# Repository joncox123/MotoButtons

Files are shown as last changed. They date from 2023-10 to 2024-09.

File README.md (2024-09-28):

# MotoButtons

## Work on MotoButtons 2 is complete. The new [repository is here](https://github.com/joncox123/MotoButtons2/tree/main).

### Updates
- 3/24/2024: MotoButtons 2 design is starting. This will include a 3D printed case with mount, commercial waterproof 4-way joystick, 3 buttons (non-LED) and separate RGB LED to indicate modes. Rechargeable LiPo battery is being considered as an option.
- 3/4/2024: Media (music) mode has been added as a forth mode.
A low cost, waterproof, Bluetooth (BLE) controller for [Drivemode Dashboard](https://www.drivemodedashboard.com/) and [MyRoute App](https://www.myrouteapp.com/) motorcycle navigation with joystick and mouse mode. The cost is only $28 in parts.

**At this time, in order to use with Drivemode Dashboard, you must [install the DMD2 beta version](https://youtu.be/bJglvH23oGI?feature=shared&t=128) from the Google Play Store. To do this, join the beta program at the bottom of the DMD2 app page in the Play Store**

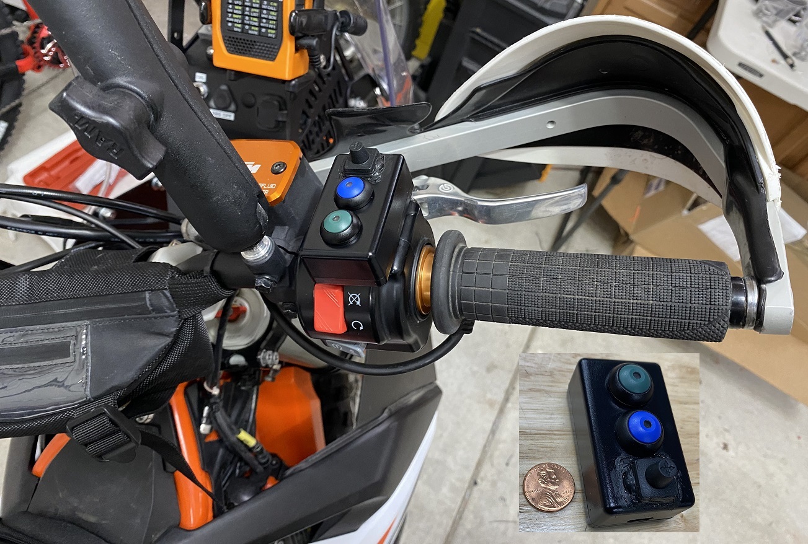
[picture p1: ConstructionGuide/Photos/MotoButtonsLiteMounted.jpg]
motobuttons lite installed on handlebar


*A more expensive version of MotoButtons will feature a IP68 rated 4-way castle switch and will be easier to construct (no sealing or fine hole drilling required), but the part will cost about $75 additional. Stay tuned*

## Why a DIY controller?
As of October of 2023, [all available controllers](https://www.drivemodedashboard.com/certified-remote-controllers/) for Drivemode Dashboard are rather expensive, especially if shipped outside of Europe, or do not offer the ideal functionality in a small size. The [least expensive controller](https://www.thorkracing.com/produto/arn-remote-pro/) that is in stock and can be shipped to the USA costs $215 USD with shipping. Since many riders have two, three or even four motorcycles, the total cost could be as high as $683, just for a set of basic controllers! However, even this controller only offers a two-way switch, so functionality is limited. 

On the other hand, an ideal controller would offer a low price, small size, light weight and a navigation switch (joystick). The joystick could be used either as a "mouse" (up/down/left/right/click) or to manipulate app functions, including Drivemode Dashboard and MyRoute App. 

MotoButtons Lite is for the DIY enthusiast who wants to construct a low cost controller. The trade off is that the Lite version requires careful drilling and gluing to construct the enclosure and waterproof the joystick.

## Cost and Parts Availability
As a DIY controller, the MotoButtons Lite has been designed with the highest quality, IP68 (waterproof) parts, while maintaining a low cost. In fact, the necessary parts can be ordered from Mouser.com for only $27.82 plus $7.99 UPS shipping. The only exception is that a low cost, IP68 rated 5-way navigation switch can not be purchased at this time ([this](https://www.digikey.com/en/products/detail/ruffy-controls-inc/HS1-6/17868372) is the least expensive I found, at $76 each). Thus, you will waterproof a $2.50 switch, which is surprisingly rugged and user friendly. In addition, you will need some epoxy glue, basic hole drilling tools and some other basic supplies, which most DIY enthusiasts will have in their garage.

## Microcontroller and Programming Experience Not Needed
No programming knowledge or skill is needed to program the Bluetooth (BLE) Arduino microcontroller. Source code and instructions are available on this site. In the future, it may be possible to provide a simple installer, but using the Arduino IDE software to upload the code is not very difficult either.

## Recommended Tools and Supplies
To build your own Motobuttons Lite, I suggest the following tools and supplies, which can be obtained at Amazon and [Harbor Freight](https://www.harborfreight.com/), for example. However, as a DIY enthusiast, you will hopefully already have many suitable tools.

- [C-POXY 30 by CECCORP](https://www.amazon.com/CECCORP-C-Poxy-30/dp/B0918TGK53)
  - Do not use a quick setting epoxy (e.g. 1 or 5 minute), as it lacks strength and sets too quickly for proper construction
- [Step drill with 35/64" diameter](https://www.harborfreight.com/2-piece-titanium-nitride-coated-high-speed-steel-step-drills-96275.html)
- [Wire size drill bit set for #56 and #60 drill bits](https://www.amazon.com/Drill-Speed-Steel-Numbered-Metal/dp/B07SW836NQ/ref=sr_1_9?crid=2E4TQN5R710MU)
  - Only needed if you don't already have #56 and #60 drill bits, such as in a 115 piece set
- [Automatic center punch](https://www.harborfreight.com/spring-loaded-center-punch-621.html)
  - For precise alignment of drilled holes to the schematic drawing template
- [Needle file set](https://www.harborfreight.com/needle-file-set-12-piece-56743.html) (Optional)
  - Needed only if you want to have external USB-C connectivity and you are potting with epoxy
- Small piece of sandpaper, such as 150 grit or similar
  - For roughening the case surface prior to gluing the navigation joystick. Can be obtained at any auto parts or home improvement store.
- Silicone sealant for waterproofing joystick
  - Black color is recommended, such as [Permatex 81158](https://www.amazon.com/Permatex-81158-Silicone-Adhesive-Sealant/dp/B000AL6WLA). Can also be found at most auto parts stores for a higher price. If you already have clear silicone, there's no need to buy additional sealant.
- Alcohol wipes or rubbing alcohol
  - For cleaning the case prior to gluing the navigation joystick. You can obtain these at any grocery or drug store, or [on the internet](https://www.amazon.com/Curad-Alcohol-Prep-Thick-Swabs/dp/B00KOSP454).
- Small gauge insulated wire
  - You'll need small gauge (e.g. 22-26 AWG) wire for soldering the microcontroller to the joystick, buttons and LEDs. If you have an old USB or serial port cable lying around, you can use the wire from there. Otherwise, you can [order wire on the net](https://www.amazon.com/Fermerry-Stranded-Colors-Flexible-electrical/dp/B089CZFDX2).
- [Soldering iron, solder and related tools](https://www.amazon.com/Soldering-Kit-Temperature-Desoldering-Electronics/dp/B07GTGGLXN)
  - You'll need an iron with a small, pointed tip and basic tools such as needle nose plyers and tweezers.

## Parts to Order
In addition to the tools and supplies mentioned above, you will need to order the parts required to construct Motobuttons Lite. [This link](https://www.mouser.com/ProjectManager/ProjectDetail.aspx?AccessID=e90304f243) will allow you to order the necessary parts from Mouser.com. Also, you can view the [formal Bill of Materials](https://github.com/joncox123/MotoButtons/tree/main/Parts) and data sheets, if interested.
-	$10.38 [Seeed Studio XIAO nRF52840 - Bluetooth 5.0](https://www.mouser.com/ProductDetail/713-102010448)
-	$5.52 [Hammond Polycarbonate Black IP68 Enclosure 1551WHBK](https://www.mouser.com/ProductDetail/546-1551WHBK)
-	$4.38 [Blue IP68 button with white LED](https://www.mouser.com/ProductDetail/655-2-2329387-1)
-	$5.09 [Green IP68 button with white LED](https://www.mouser.com/ProductDetail/655-1-2329387-6)
-	$1.95 [5-way Navigation Joystick Switch](https://www.mouser.com/ProductDetail/485-504)
-	$0.50 [Rubber boot for joystick](https://www.mouser.com/ProductDetail/485-4697)

## Instructions
Complete [step-by-step instructions](https://github.com/joncox123/MotoButtons/tree/main/ConstructionGuide) for building your own MotoButtons Lite are available. If you have questions, concerns or suggestions, [please create a new issue](https://github.com/joncox123/MotoButtons/issues) in this GitHub repository.

### User Guide
Operation is simple, but [see the user guide.](https://github.com/joncox123/MotoButtons/blob/main/UserGuide/readme.md)

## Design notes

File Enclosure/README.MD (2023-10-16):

This directory contains instructions and schematics for modifying the Hammond 1551WHBK black polycarbonate, IP68 rated (waterproof) enclosure to install the buttons and USB-C connector (or power wires).

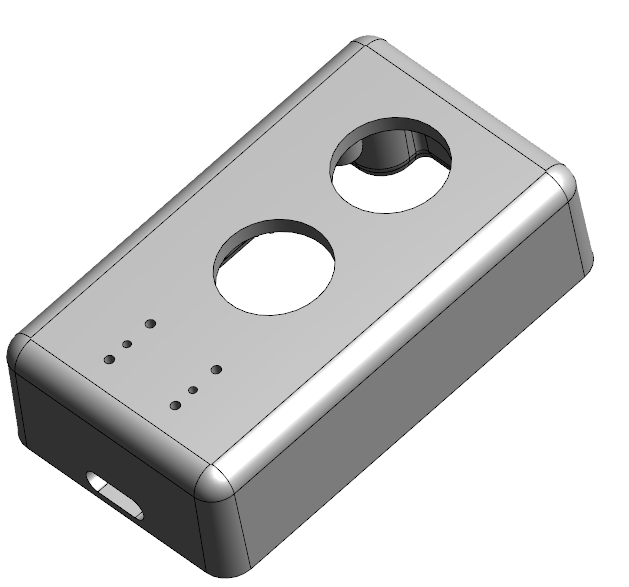
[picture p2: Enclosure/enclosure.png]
3D model of modified case


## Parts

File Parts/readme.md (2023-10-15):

# Parts (Bill of Materials)
This directory contains the Bill of Materials (BOM) needed to build your own Motobuttons Lite Bluetooth controller. All parts can be ordered from [mouser.com via this shared cart link](https://www.mouser.com/ProjectManager/ProjectDetail.aspx?AccessID=e90304f243).

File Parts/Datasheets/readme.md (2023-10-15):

This directory contains the data sheets for the parts needed to construct the enclosure.

For information on the microcontroller, see the [Seeed Studio page](https://www.seeedstudio.com/Seeed-XIAO-BLE-nRF52840-p-5201.html).

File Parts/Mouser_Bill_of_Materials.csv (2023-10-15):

SHOPPING CART
This is not an invoice
15-Oct-23 17:13:10
 | Mouser # | Mfr. # | Manufacturer | Customer # | Description | RoHS | Lifecycle | Order Qty. | Price (USD) | Ext.: (USD)
1 | 713-102010448 | 102010448 | Seeed Studio |  | Bluetooth Development Tools - 802.15.1 Seeed Studio XIAO nRF52840, MicroPython - Bluetooth 5.0 |  | New At Mouser | 1 | $10.38 | $10.38
2 | 546-1551WHBK | 1551WHBK | Hammond |  | Enclosures, Boxes, & Cases Watertight plastic enclosure | RoHS Compliant | New Product | 1 | $5.52 | $5.52
3 | 655-2-2329387-1 | PB6B2FM7M1CAL01 | TE Connectivity |  | Pushbutton Switches PB OFF/ON FC Blue White LED IP68 | RoHS Compliant By Exemption |  | 1 | $4.38 | $4.38
4 | 655-1-2329387-6 | PB6B2FM6M1CAL01 | TE Connectivity |  | Pushbutton Switches PB OFF/ON FC Green White LED IP68 | RoHS Compliant By Exemption |  | 1 | $5.09 | $5.09
5 | 485-504 | 504 | Adafruit |  | Adafruit Accessories Thru-hole 5-way Navigation Switch | RoHS Compliant |  | 1 | $1.95 | $1.95
6 | 485-4697 | 4697 | Adafruit |  | Joysticks Black Rubber Joystick Nubbin Cap for Navigation Joystick |  |  | 1 | $0.50 | $0.50
By submitting your order you agree to these terms and conditions. |  |  |  |  |  |  |  |  | Merchandise: | $27.82
Prices are reflected at the date and time shown. |  |  |  |  |  |  |  |  | Shipping Charge: | $7.99

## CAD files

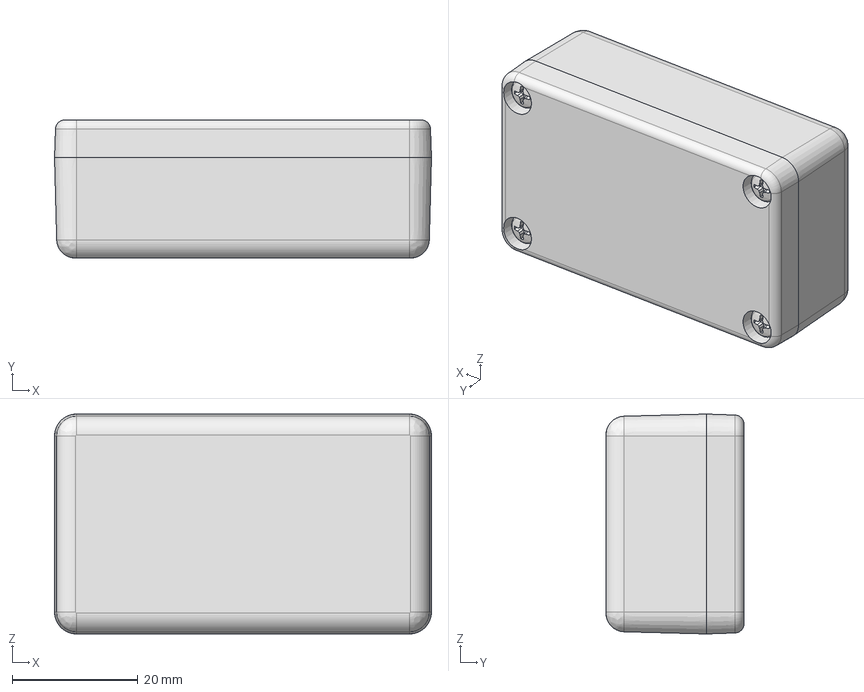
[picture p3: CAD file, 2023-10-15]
Parts/Datasheets/1551WHBK.stp
60.0 x 22.0 x 35.0 mm
1551WH Bottom
1551WH Lid
1551W (35X60) Gasket

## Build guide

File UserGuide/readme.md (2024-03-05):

# User Guide
## Pairing with your phone
When MotoButtons is first powered on, both button LEDs will flash rapidly until the device is paired with your phone. If pairing is ever lost during use, they will start flashing again.

To pair with your phone, power up MotoButtons and ask your phone to pair with the Bluetooth device named "DMD2 CTL 8K" by navigating to Bluetooth pairing in the phone's Settings. This name is chosen for compatibility with the Drivemode Dashboard beta app. Once paired with your phone, it should quickly auto-connect when powered on again. 

## Cycling Through Modes
MotoButtons supports multiple modes of operation, including:
1. Mouse cursor mode
2. Drivemode Dashboard 2 mode
3. MyRoute App mode
4. Media (music) mode

MotoButtons can be cycled through these modes, in that order (Mouse->DMD2->MRA->Media) by holding down both A and B buttons for 1 second. When advancing the mode, both LEDs will flash rapidly for 2 seconds. Then LED A will flash to indicate the mode number (one flash for mouse, two flashes for DMD2, three flashes for MyRoute App). 

The mode state will be saved so that the last mode prior to power down will be activated at the next power up. In other words, if you keep your MotoButtons set to MyRoute App mode, it will remember that when you use it next. Upon boot, the mode will be indicated by flashing the mode number.

## Button Mapping
This section describes the button mapping for each mode.

### Mouse Mode
Mouse mode is simple. The joystick moves the mouse cursor. Pressing the center of the joystick will simulate a left click. In addition, pressing Button B will also simuilate left click. Pressing Button A will simulate hitting the enter key on a keyboard. 

### Drivemode Dashboard 2 Mode
The joystick controls up/down/left/right, accordingly. A button activated F5, B button F6 and long pressing the joystick center activates F7.

### MyRoute App Mode
First, you must set MyRoute App to use the "BarButtons" controller. This provides the necessary functionality and MyRoute App will interpret the button presses correctly.

When in MyRoute App mode, the joystick will pan the map view. Buttons A and B will zoom the map view in and out. Tapping the joystick center button will center the map. Long pressing the joystick center will activate the menu. In theory, continuing to hold the joystick center button should skip waypoint.

### Media (music) Mode
This mode allows you to control your music. Press up or down on the joystick to change the volume. Pressing the joystick center will mute. Press left or right on the joystick to go to previous or next track, respectively. Button A will play or pause the music, while button B will stop all music.

## Rotating the Orientation
Since MotoButtons may be installed on the motorcycle in any orientation, it is sometimes necessary to rotate the orientation of the joystick. This can be done by holding down the joystick in the direction you want to be the new "up" direction, while powering on. In other words, let's say you want to mount the device upside down. Then you would press "down" on the joystick (it will now be upward when mounted upside down), then while holding this direction, apply power to the device. The change should be stored within a couple of seconds. 

At subsequent power cycles, the settings, including orientation, will be remembered and loaded.

## Updating the Software
To update the software on the microcontroller with a new release of MotoButtons, you may need to reset the controller to put it into Device Firmware Update (DFU) mode. This can be done by holding down buttons A and B for 10 seconds. This is the same procedure for changing the mode, except you must hold them down together for 10 seconds instead of only for one second.

There is a bug in the microcontroller's bootloader firmware that can sometimes prevent new MotoButtons software releases from being uploaded via the Arduino IDE, unless a special reset is performed. If this happens, the IDE will fail to upload new "sketches" (software code) by either timing out or printing a DFU (Device Firmware Update) error message. This could be especially problematic if you filled the case with epoxy (potting) or cannot access the tiny reset button on the microcontroller. Otherwise, it is necessary to quickly double tap the tiny reset button in order to manually enter DFU (software update) mode again.

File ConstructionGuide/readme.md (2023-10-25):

# Construction (building your MotoButtons Lite)
Building your own MotoButtons Lite requires no programming experience, only relatively basic hand tools and DIY skills. However, if you are not moderately competent at soldering, working with glue and sealants and drilling precision holes, you might want to ask a friend for help. 

## Be Prepared
### Disclaimer
No warranty or implied fitness for any use is provided and the authors assume no liability for any failures or accidents that occur. You assume all risk of building or operating MotoButtons. The controller should never be used while the vehicle is in motion to reduce the risk of a collision or accident. Operating a motorcycle, working with tools and chemicals is an inherently dangerous activity and should only be attempted by qualified and experienced people. By proceeding, you agree to assume all risk associated with construction and operation of MotoButtons.

### Gather Supplies and Tools
First, you'll need to acquire the necessary components, tools and supplies, as mentioned on the [main page](https://github.com/joncox123/MotoButtons/tree/main#recommended-tools-and-supplies). Most DIY enthusiasts will have many of these tools and supplies, except for the parts from Mouser, the slow curing epoxy, and the necessary drill bits.

## Let's Get Started
### Machine the Enclosure
First, you need to make the necessary modifications to the Hammond IP68 rated enclosure. While I used a milling machine to do this, it's readily possible with the proper hand tools, technique and attention to detail. At the end of the day, it is not necessary for everything to be perfect. The sealant, joystick boot and buttons will cover up any minor issues.
Take a look at the [3D model (3D PDF)](../Enclosure/MotoButtons%20Lite%20Enclosure%201551WH%20Bottom%203D.pdf) to get an idea of what you will be doing.

3D model of modified case

If you happen to have a milling machine, you can clamp the enclosure (with lid screwed on) in a vise with three layers of duct tape above the parallels.

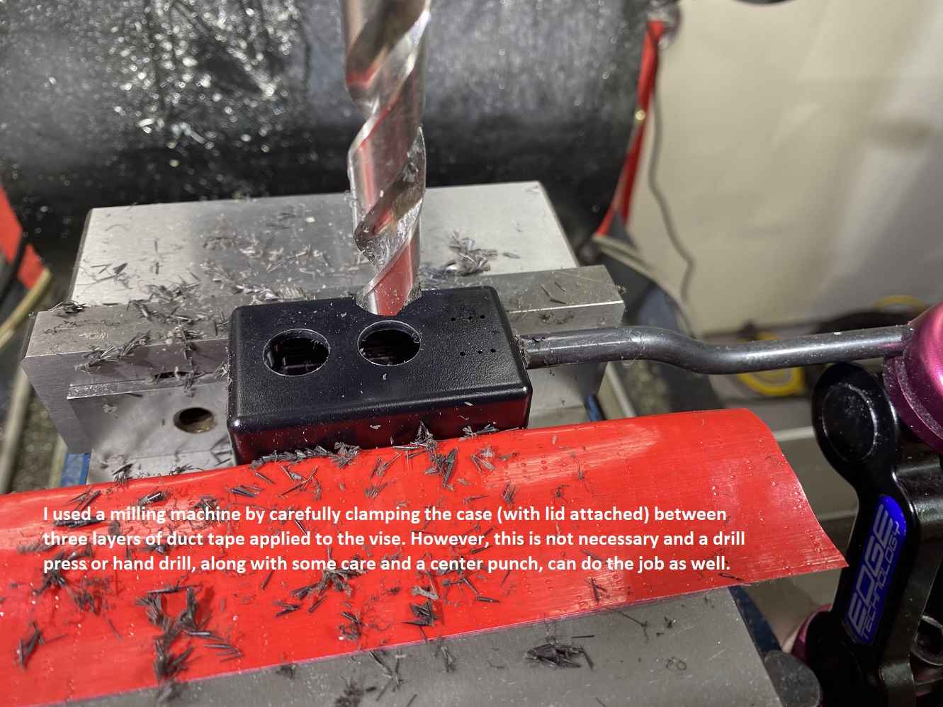
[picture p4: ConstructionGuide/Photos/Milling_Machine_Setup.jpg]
case in milling machine


First, print out the [schematic drawing](../Enclosure/MotoButtons%20Lite%20Enclosure%201551WH%20Bottom.pdf) of the enclosure, making sure to print as "actual size", so that the print is scaled exactly as indicated. You may want to check the dimensions with a caliper or ruler to verify that you printed it out true to scale. 

<a href="../Enclosure/MotoButtons%20Lite%20Enclosure%201551WH%20Bottom.pdf">
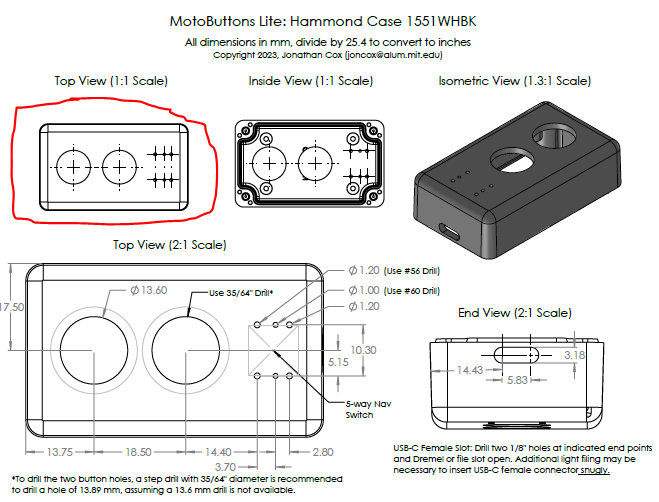
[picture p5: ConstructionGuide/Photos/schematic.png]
diagram of modified case
  
</a>

Cut out the top left diagram titled "Top View (1:1 Scale)" and carefully tape it over the top of the enclosure. Do your best to center it on the case and avoid any wrinkles in the paper. Use an automatic center punch to very precisely create indentations (divots) on the center of each of the 8 holes. This can be done by placing the tip of the center punch directly over the center markings of each hole and pressing down. You might want to practice this step on a piece of plastic or wood as it is easy to misjudge the center of the punch. 

After you have created the eight marks, carefully clamp the case in a vise [recommend soft vise jaws](https://www.amazon.com/HORUSDY-Universal-Magnetic-Retention-Urethane/dp/B078MVLSZS) and drill the two large button holes (on the mark centers) with a small pilot drill about 1/8" diameter. When clamping the case, keep in mind that it is strong, but polycarbonate can suddenly crack if too much force is applied. Tighten the vise just enough to hold the case securely when moved by hand. After drilling the pilot holes, drill both holes out to 36/64" using a step drill. Set your hand drill or drill press to a low speed for this step to avoid chatter. 

Finally, you will drill the small holes for the electrical pins of the 5-way navigation switch (joystick). This step is challenging to do with a hand drill because the small drill bits tend to break easily with the slightest deflection--so be careful and wear safety glasses. The upper and lower holes will use the #56 bit, and the two "middle" holes will use the smaller #60 bit. **Notice that the two "middle" holes are not exactly in the middle. The orientation of the switch matters!**  When you are done, your case should look as follows:

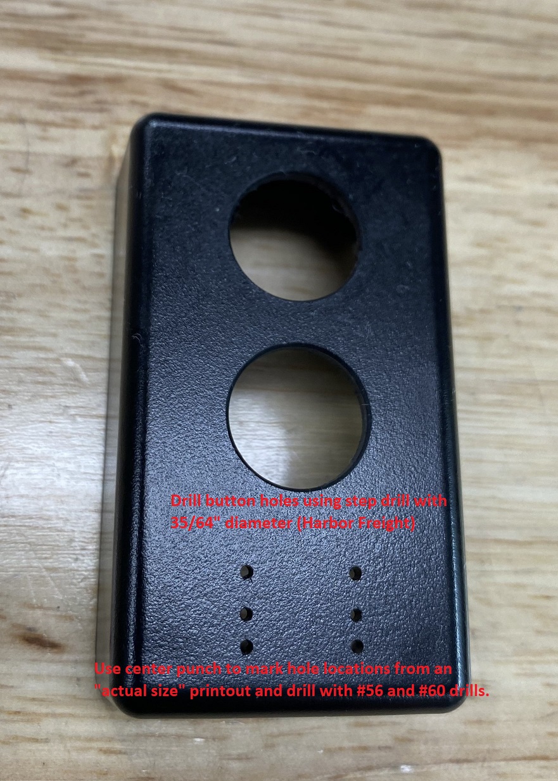
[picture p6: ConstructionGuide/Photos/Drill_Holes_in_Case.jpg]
Top of case with holes drilled


Before proceeding, test fit the buttons and the navigation switch. **Caution: the switch must be inserted in the six holes with the correct orientation! The two middle holes are closer to one side.**

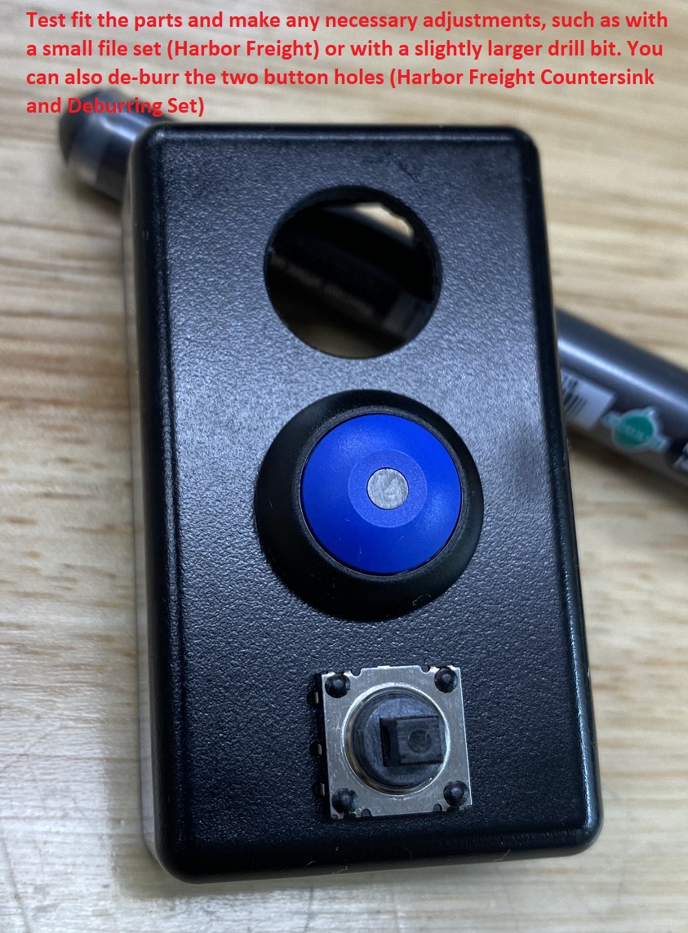
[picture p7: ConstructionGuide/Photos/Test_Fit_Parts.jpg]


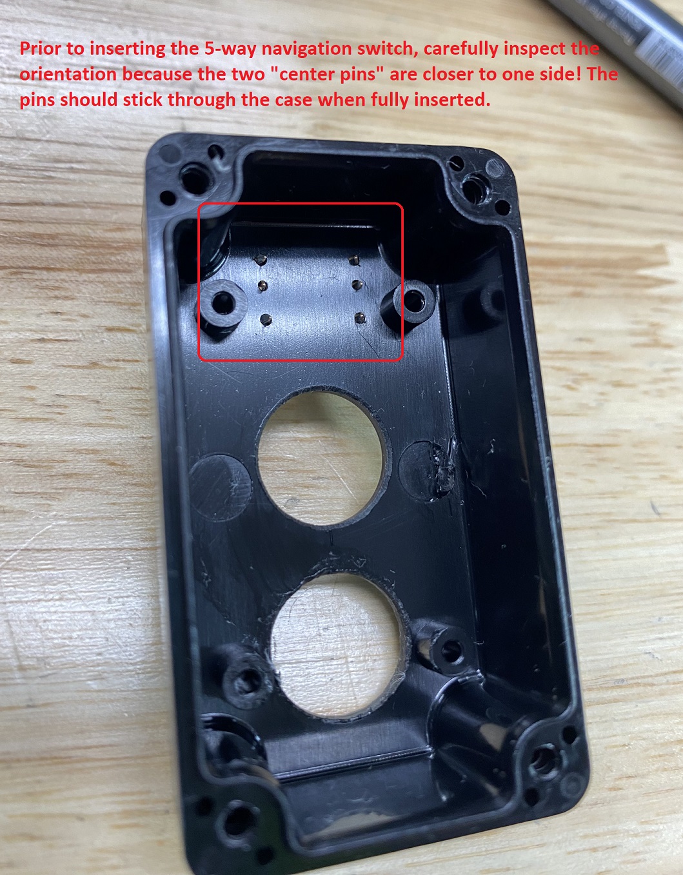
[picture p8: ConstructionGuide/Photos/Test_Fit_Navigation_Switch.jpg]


### Cut Off the Circuit Board Posts (Optional)
If you ordered the buttons with screw thread mounting, as opposed to the snap on ones, you'll need to cut off two of the PCB mounting posts on the inside of the case. Otherwise, you won't be able to properly tighten the nut to secure the top button. It's possible to omit this step by ordering the snap in buttons, but the waterproofing won't be as good unless you are also potting the case with epoxy. 

**Nevertheless, if you are going to pot with epoxy, you could simply tighten the nut the best you can without cutting off the posts, and skip this step.**

Use a dremel with a small cut off wheel to cut off the upper posts. Then sand the area flat using a sanding wheel. *I used a milling machine and a 7/32" end mill to do this step, so it might be a good idea to omit this step unless you are confident in your abilities and tools.*

## Power Entry
This section describes two options for power the device. By the way, this microcontroller has integrated functionality for charging a lithium battery. While this guide does not describe such a version, it could be easily built by soldering a small battery to the proper terminals.

### Drill Hole for Power Wires (Option 1, Recommended)
The easiest option to power the device, which does not require machining a slot for the USB-C connector, is to drill a hole on the end for the power wires. This option is also the easiest to seal, as after you run the wires through the end of the case, you only need to apply a bit of sealant on the inside and outside of the wires. 

Since the microcontroller requires 5 Volt power, the easiest way to power it is via an old USB cable, assuming you also have a USB port on your bike. Thus, you could take an old cable, cut the end off, and solder the ground and power wire to the GND and 5V pads on the microcontroller, as described near the end of this guide.

### Machine the USB-C Connector Slot (Option 2, Not Recommended at this Time)
If you are planning to epoxy fill (pot) the enclosure, for the ultimate in durability and waterproofing, you may wish to cut a slot for the USB-C connector on the microcontroller. This will allow you to update the firmware in the future, should additional functionality become available (or if you wish to modify the source code yourself). **However, I do not recommend potting with epoxy just yet because of a bug in the microcontroller firmware that requires hitting the reset button twice to upload new firmware. Update: a solution to this issue has been implemented, which requires holding down buttons A and B for 10 seconds to trigger a software reset into DFU mode. However, please wait until further testing is completed before potting with epoxy.**

The slot for a female USB-C connector is approximately 1/8" (3.18 mm) tall and 9 mm wide (end to end). Therefore, using the center punch, mark two horizontally spaced holes that are 5.83 mm apart by printing out the template and using a center punch or using a caliper. Drill both holes with a 1/8" drill bit. Using a needle file set, carefully file out the slot. You will need to test fit the slot with the microcontroller, as shown below. This will require some trial and error, as it is necessary to file the ends using the round file and the straight edges with a flat file until the connector fits snuggly. I used a milling machine with a 1/8" endmill to do this, although I still had to do manual filing to get the connector to fit.

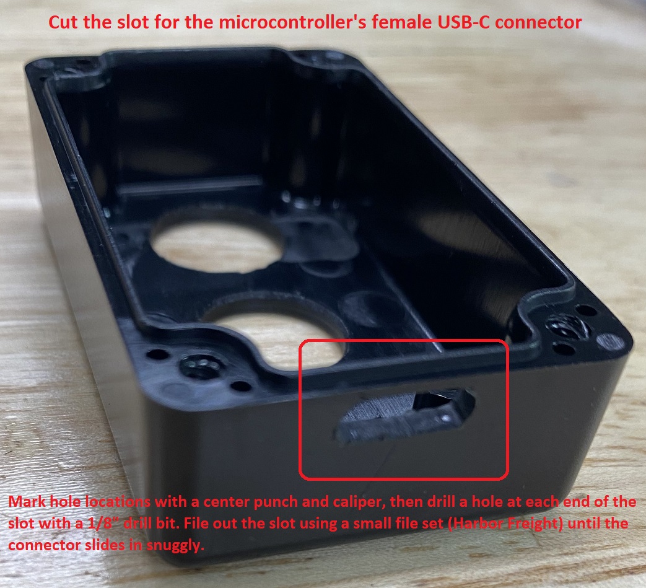
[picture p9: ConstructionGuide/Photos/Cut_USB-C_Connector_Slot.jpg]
USB-C slot in enclosure


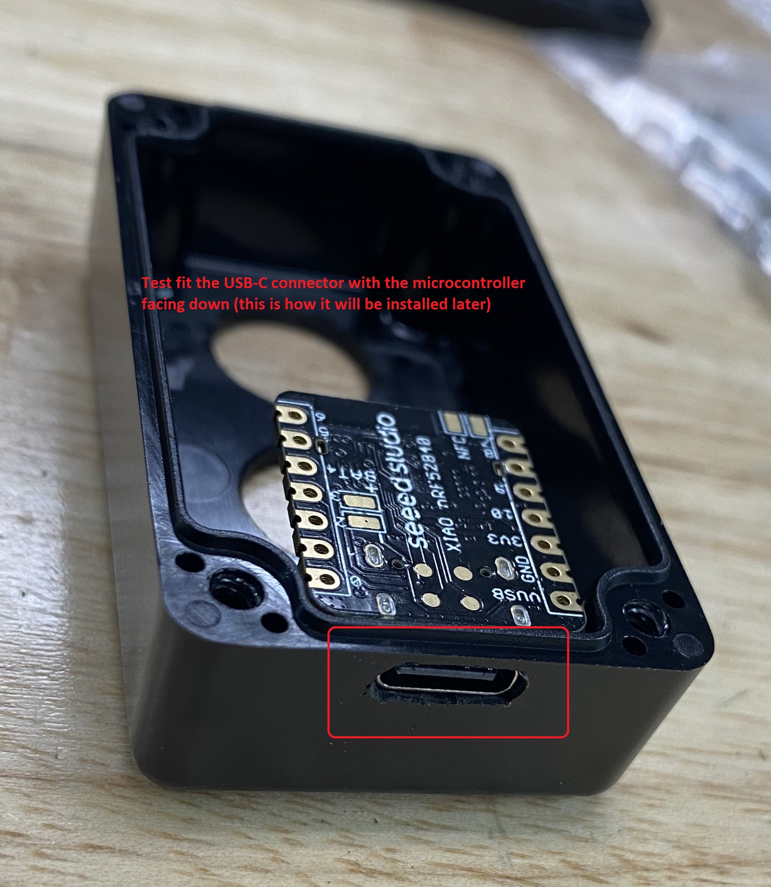
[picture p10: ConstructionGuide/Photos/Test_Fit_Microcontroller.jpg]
Microcontroller in USB-C slot


## Glue 5-Way Navigation Switch to Case
Congratulations, you've successfully machined your enclosure! The next step is to glue the joystick to the outside of the case using epoxy glue, and then seal the rubber boot over it with silicone sealant. Begin by assembling your gluing and sealing supplies:

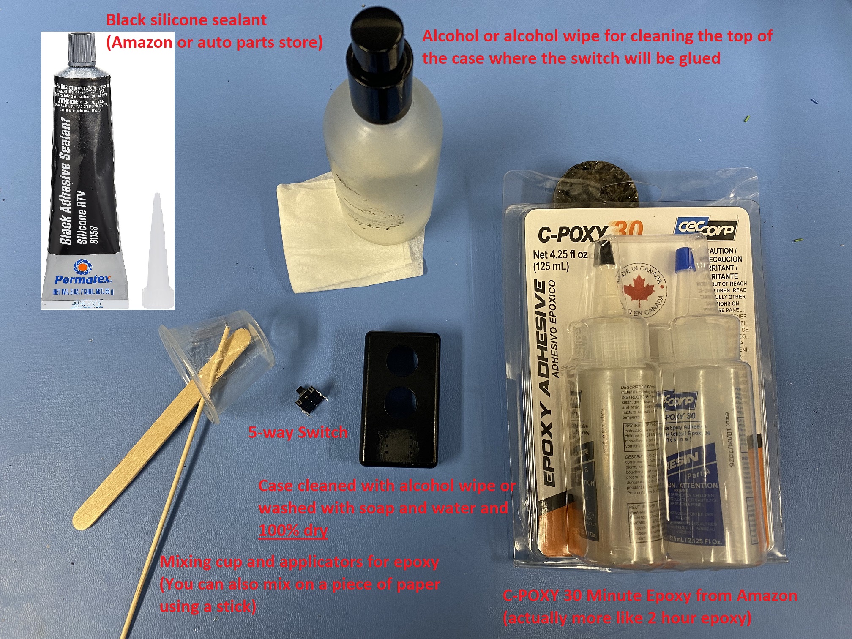
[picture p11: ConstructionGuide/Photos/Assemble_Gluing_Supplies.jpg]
gluing supplies


First, lightly sand the area on the case where the switch will sit with some 150 grit or similar sand paper. This will help the epoxy stick to the case. Then *very throroughly clean* the case with an alcohol wipe or rubbing alcohol. Blow off any lint that remains. You may also want to wipe down the bottom and sides of the switch with alcohol, especially if you have been handling it. Preparation is key to achieving a durable and waterproof bond. 

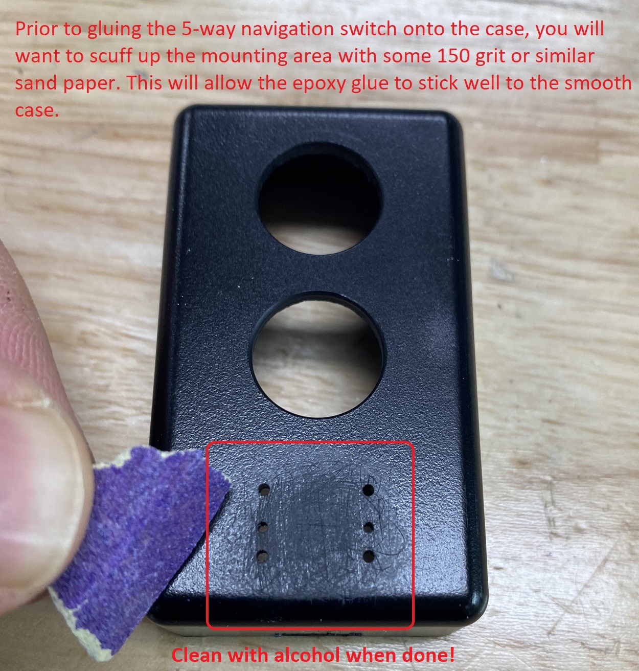
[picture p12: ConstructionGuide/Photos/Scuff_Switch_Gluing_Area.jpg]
sanding case


Mix up a small amount of C-POXY 30 two-part epoxy. This epoxy has an approximately 10 minute working time and takes about two hours to cure (full cure in 24 hours). Using a small stick or applicator, carefully spread a thin layer between the holes on the case, being **careful not to apply epoxy over the holes.** Also apply a **thin layer** of epoxy to the underside of the switch. *Note: the amount applied in the photos is more than you need, just use a thin layer*. 

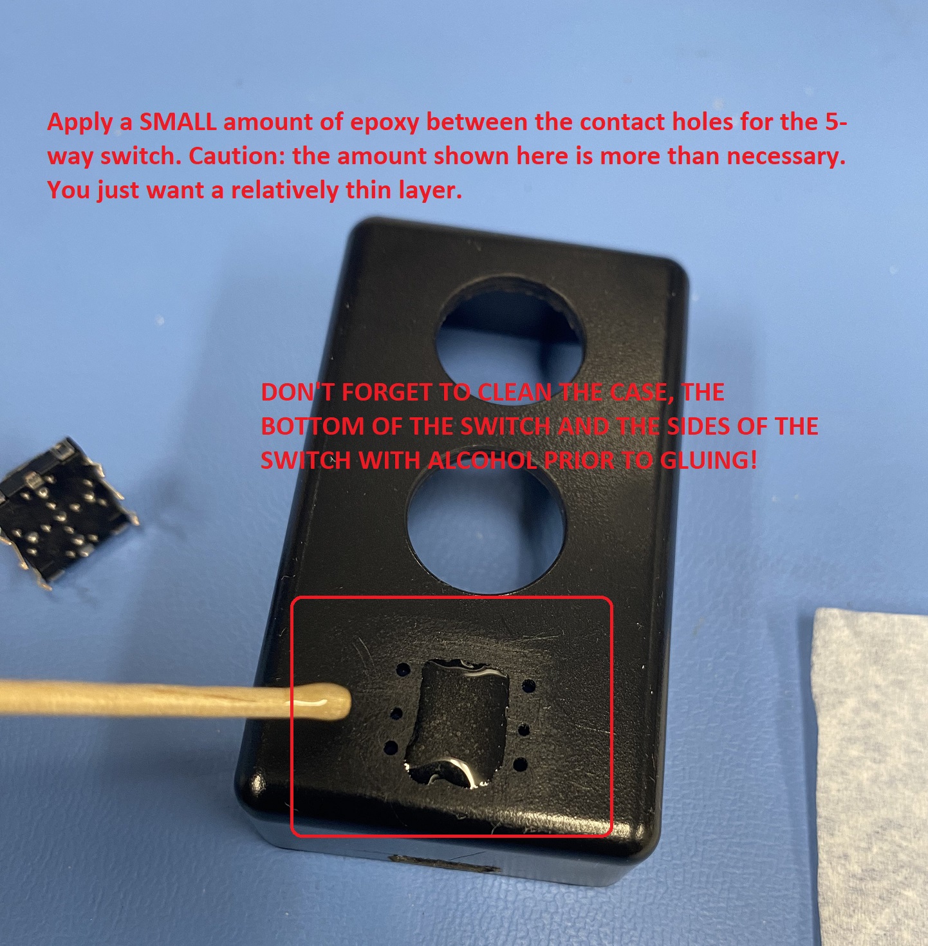
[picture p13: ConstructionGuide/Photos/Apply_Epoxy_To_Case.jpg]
epoxy on case


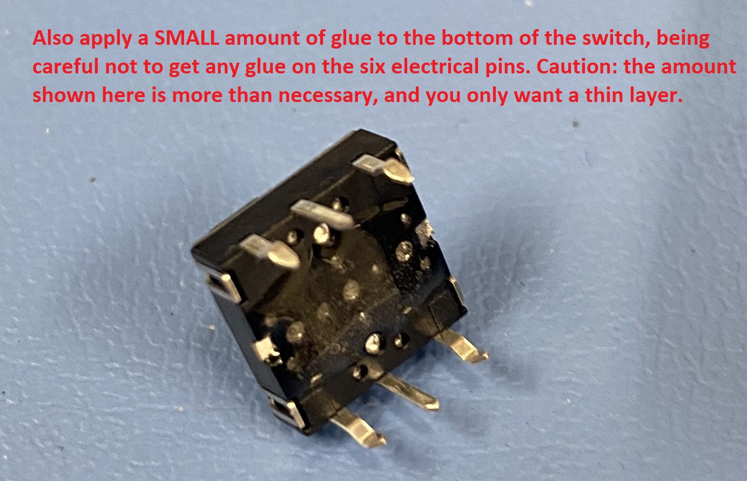
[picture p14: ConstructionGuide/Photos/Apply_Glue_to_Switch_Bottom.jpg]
epoxy on switch


Insert the switch to the holes of the case, making sure not to get any epoxy on the electrical pins. **Observe the proper orientation of the switch, as it is not symmetric top to bottom. The two holes in the "middle" are closer to the bottom side (away from buttons), so line them up before inserting**. A little epoxy should squish out the sides, and you can wipe additional epoxy along the sides of the switch, being careful not to get any on the upper portion (and ruining the mechanism). The idea is to wipe epoxy along the sides and the case surface so that it holds along the perimeter.  

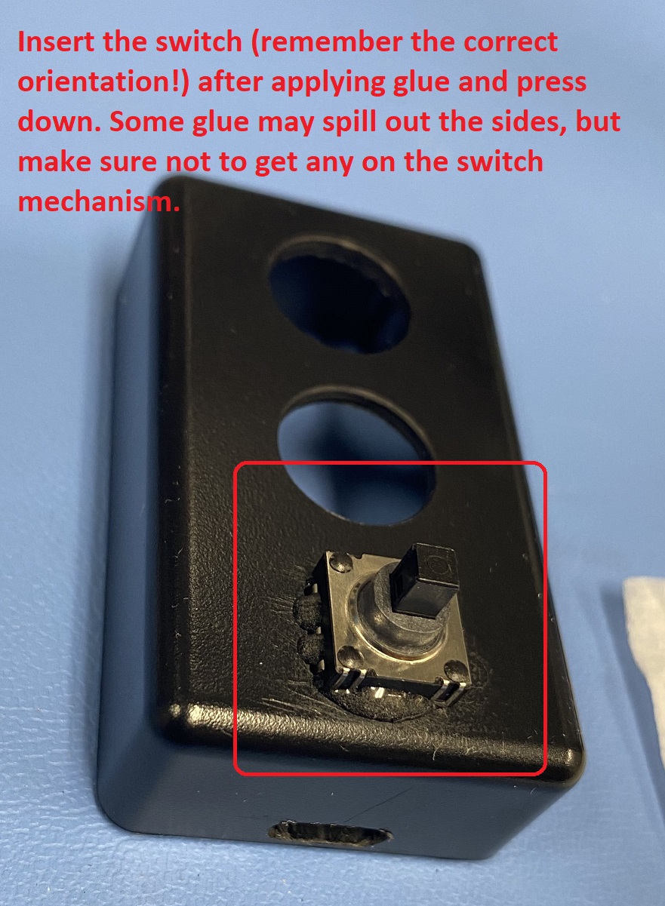
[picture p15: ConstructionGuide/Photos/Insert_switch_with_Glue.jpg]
epoxy squishing out of switch and case


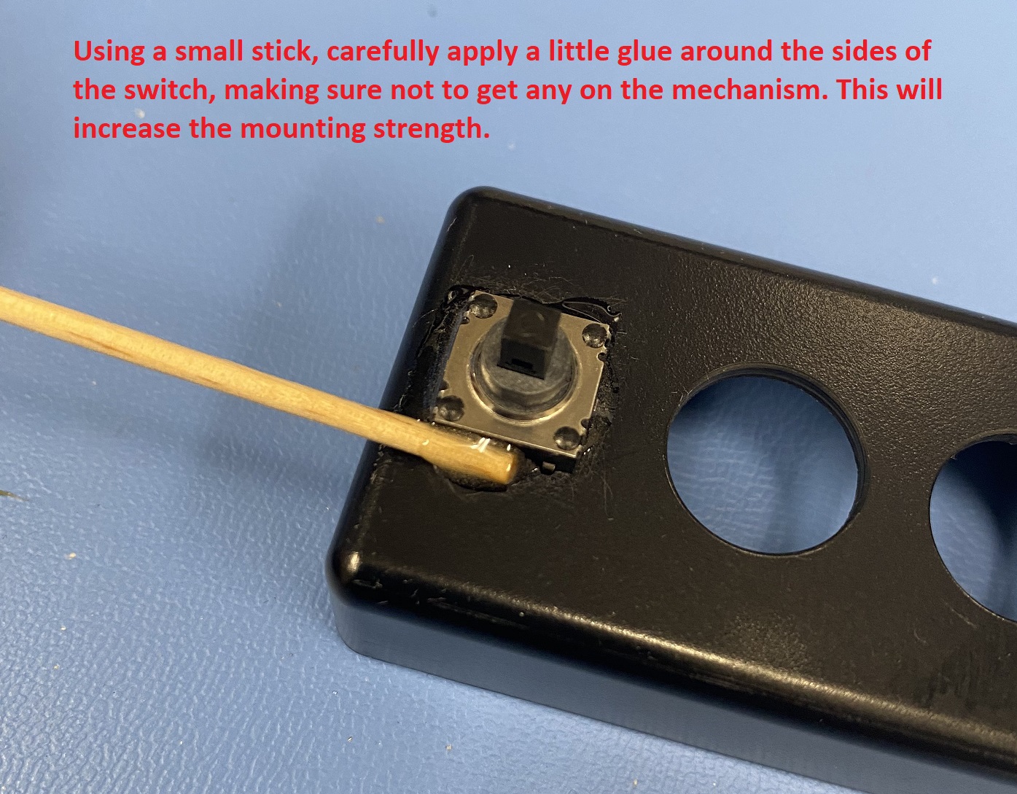
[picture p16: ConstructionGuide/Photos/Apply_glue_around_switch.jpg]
wipe epoxy around switch


When you are finished applying epoxy, it should look as follows. **You will want to proceed to install the boot, seal the boot and then cure the enclosure upside down fairly quickly, to avoid having epoxy run down the pin holes and cover the electrical contacts.**

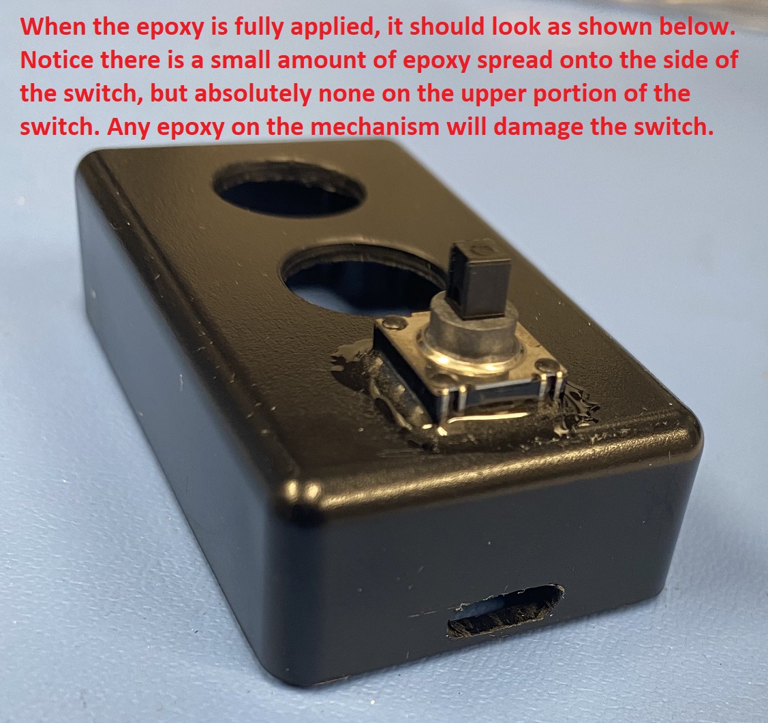
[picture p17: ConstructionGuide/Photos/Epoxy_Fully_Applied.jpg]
epoxy completely applied


### Install Rubber Boot over 5-way Switch
Before the epoxy begins to cure (within a couple of minutes), you will want to install the rubber boot over the joystick. To do so, simply press the cap over the switch with a bit of force. Also press around the perimeter of the cap, near the base, so seat it over the base. It requires a little bit of work to get it fully seated. 

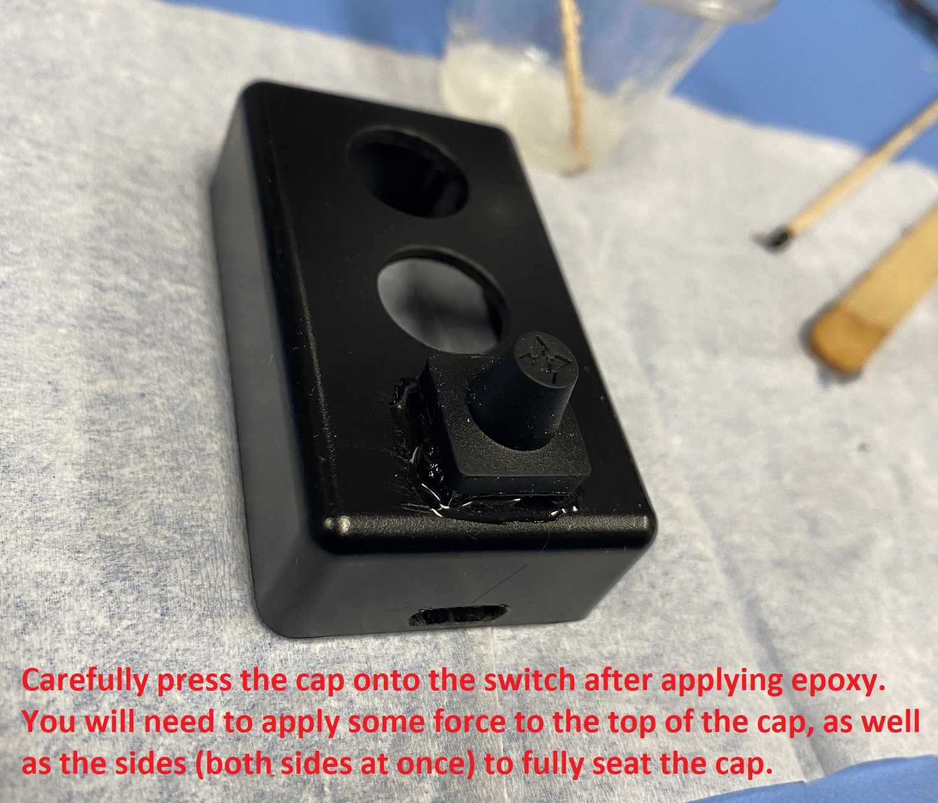
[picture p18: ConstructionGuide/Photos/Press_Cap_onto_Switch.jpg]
cap inserted onto switch


After seating the switch, take your silicone sealant and use another small applicator stick to spread sealant around the edge of the boot and the case surface. However, be careful not to get it too close to where you will install the button. Look carefully around the boot to make sure there are no bubbles and there is a generous amount of sealant around the entirety of the base of the boot, extending to the case.

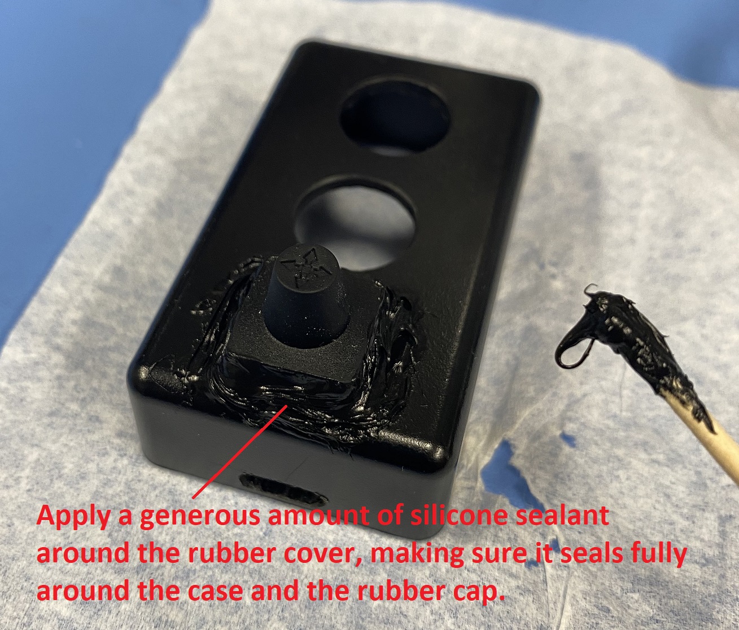
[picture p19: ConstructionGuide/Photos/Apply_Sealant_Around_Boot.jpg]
sealing boot with silicone


When you are satisfied, you can gently wipe all four sides with your fingers to smooth out the appearance, but this is not necessary (for asthetic purposes only). Be carefull not to press too hard because you want a generous amount of sealant to remain. 

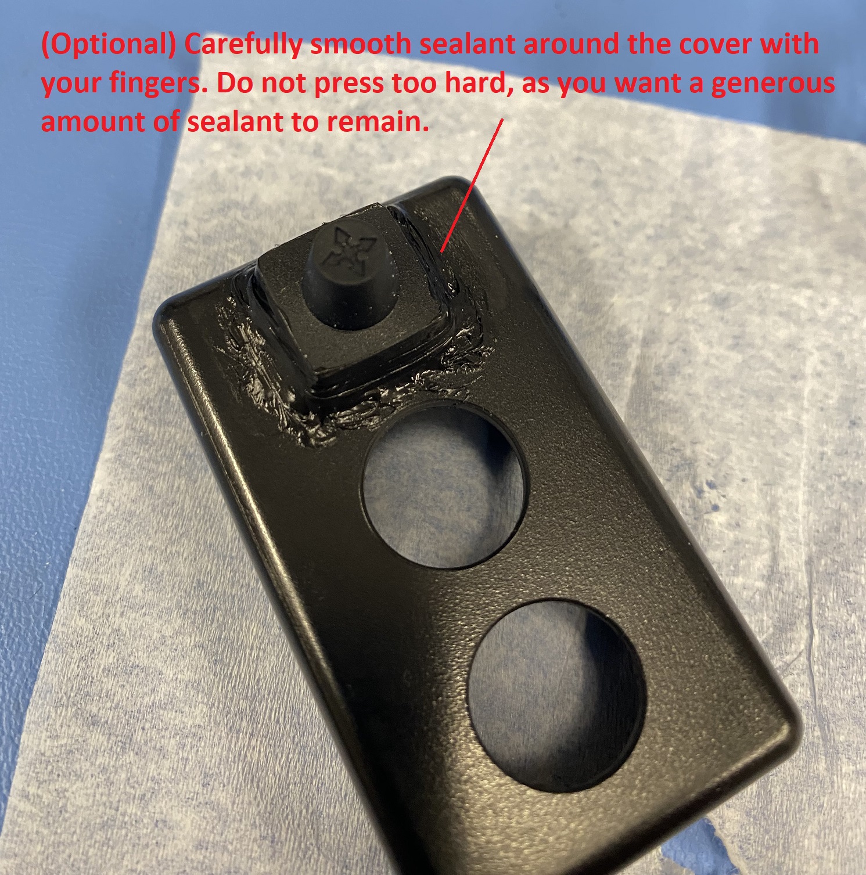
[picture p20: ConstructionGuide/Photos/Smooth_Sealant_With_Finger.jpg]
smooth sealant


When everything is completed, it should look as follows. Quickly proceed to the next step to cure it upside down.

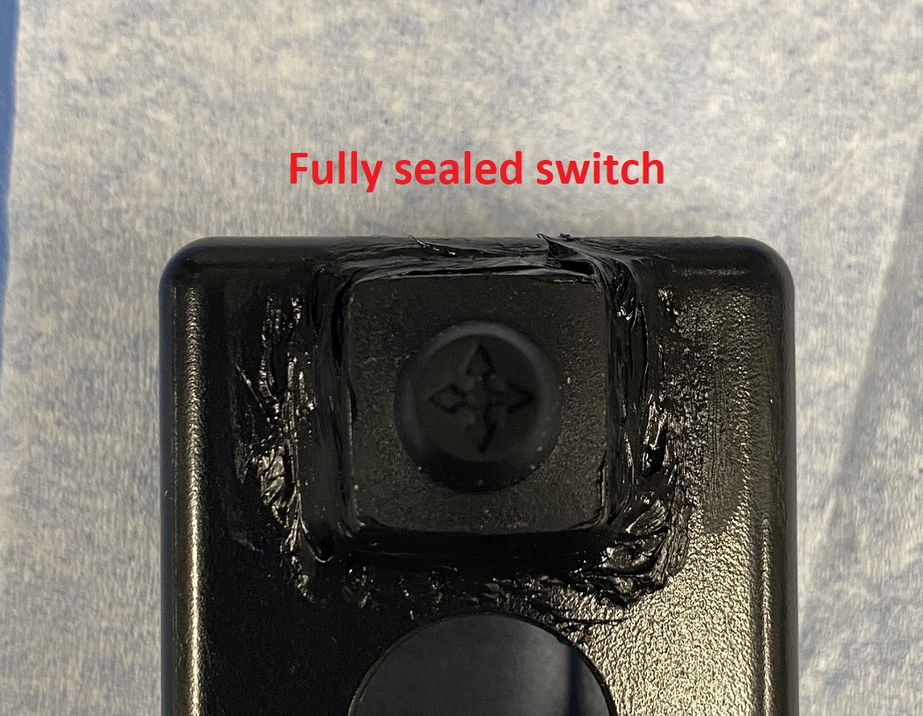
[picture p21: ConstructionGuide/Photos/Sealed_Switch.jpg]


**Turn the case upside down so that it is supported by the switch boot.** Prop up the other side with some material. You can place objects or the epoxy bottles on either side of the case to keep it from tipping over. Place some sort of weight on the case to provide a bit of pressure to cure the switch flush to the case. While the epoxy is mostly cured after about 2 hours, the silicone will take 24 hours, so let the entire arrangement rest undisturbed for 24 hours before proceeding.

You can see in the following photo that I applied a bit too much epoxy, and didn't turn upside down soon enough. As a result, some epoxy began to run down the pins, although there is still some exposed metal that I can solder to.

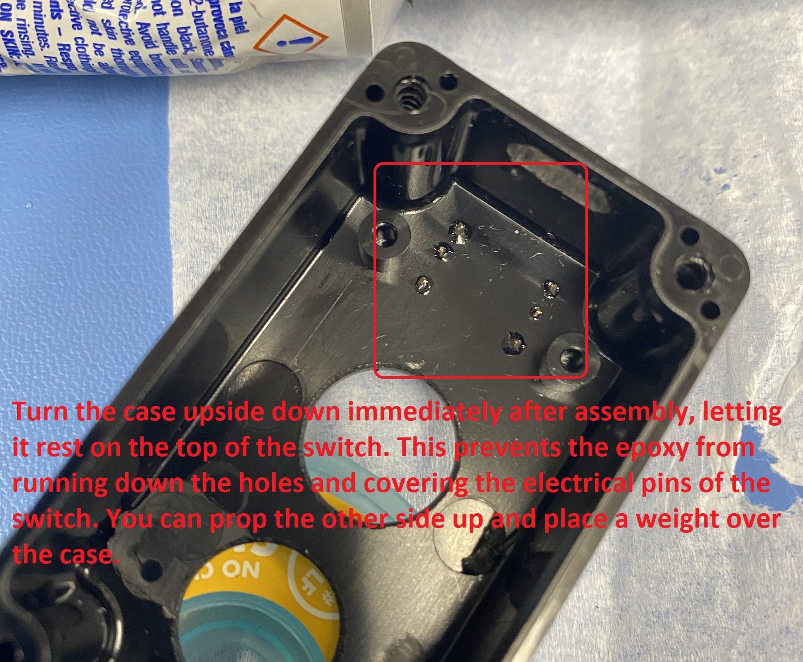
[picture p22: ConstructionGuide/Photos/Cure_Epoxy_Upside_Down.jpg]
cure upside down


## Installing Buttons and Soldering Wires
First, install the two buttons. Place the O-ring in the groove, then insert the buttons into the case. Place the lock washer and the nut over the back of the buttons and tighten gently (but firmly) with a 14 mm socket. **Make sure to align the buttons such that the two *shorter* wire leads face inward. These are the LED negative (-) terminals.**

### Soldering Wires to 5-Way Switch
With some color coded small gauge wire (approximately 26 AWG), "tin" each of the six pins and six wire segments of about 4 cm each. Solder the wires to each of the six pins. The switch pinout is shown in the photo below. Looking from the inside of the case, with the two buttons oriented up, the pinout clockwise from the upper left pin is: center, up, left, down, common, right. If viewed from the outside front of the case, the "left" pin will be on the left side and the "up" pin will face up, assuming the two buttons are on the top (direction of arrow). 

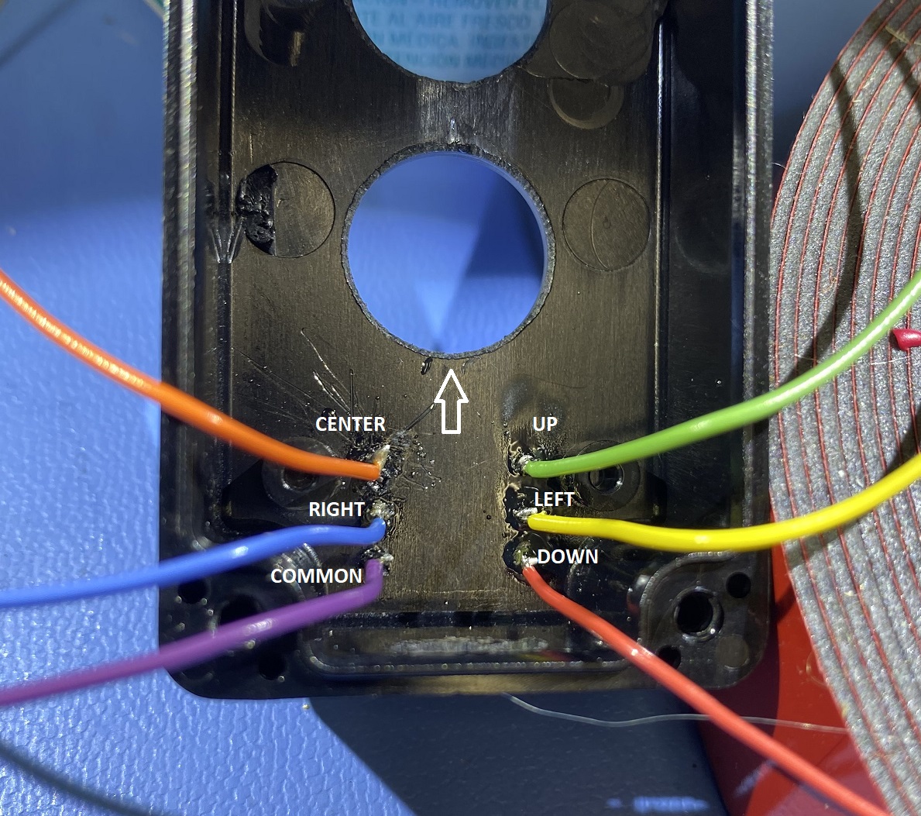
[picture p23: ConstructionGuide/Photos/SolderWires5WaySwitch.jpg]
soldering wires to 5-way switch and pinout


### Solder Wires to Buttons and Button LEDs
Make sure the buttons are rotated so that the two shorter leads face inward. These are the LED negative (-) pins that you will connect to ground. Solder wires to each of the button leads, except **bridge the two short LED leads together by soldering both with a single ground wire (see photos).** 

Also, you may want to put a piece of heat shrink tubing over the bottom most LED wire for Button B. This can prevent it from shorting out on either the microcontroller or the other pins on the button. If you don't have a small diameter piece of heat shrink, you can put a bit of electrical tape around it.

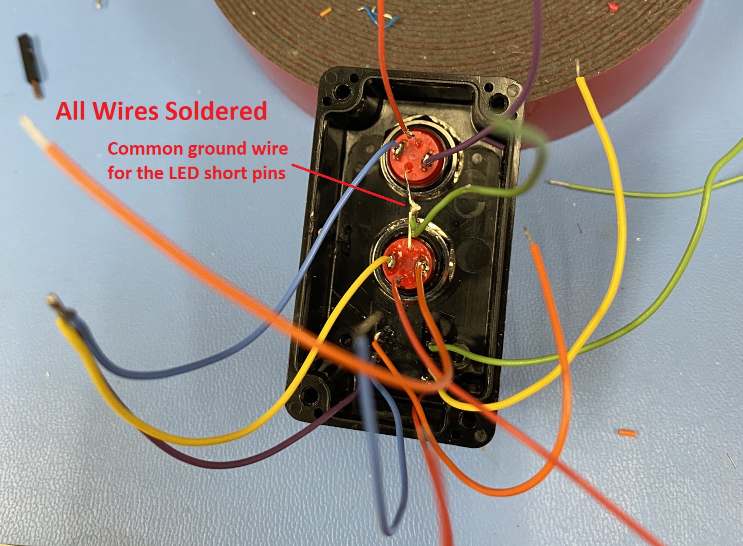
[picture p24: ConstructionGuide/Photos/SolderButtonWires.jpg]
all wires soldered to buttons and joystick


## Solder All Wires to Microcontroller
Study the [wiring diagram](CaseConnections.pdf) shown below:

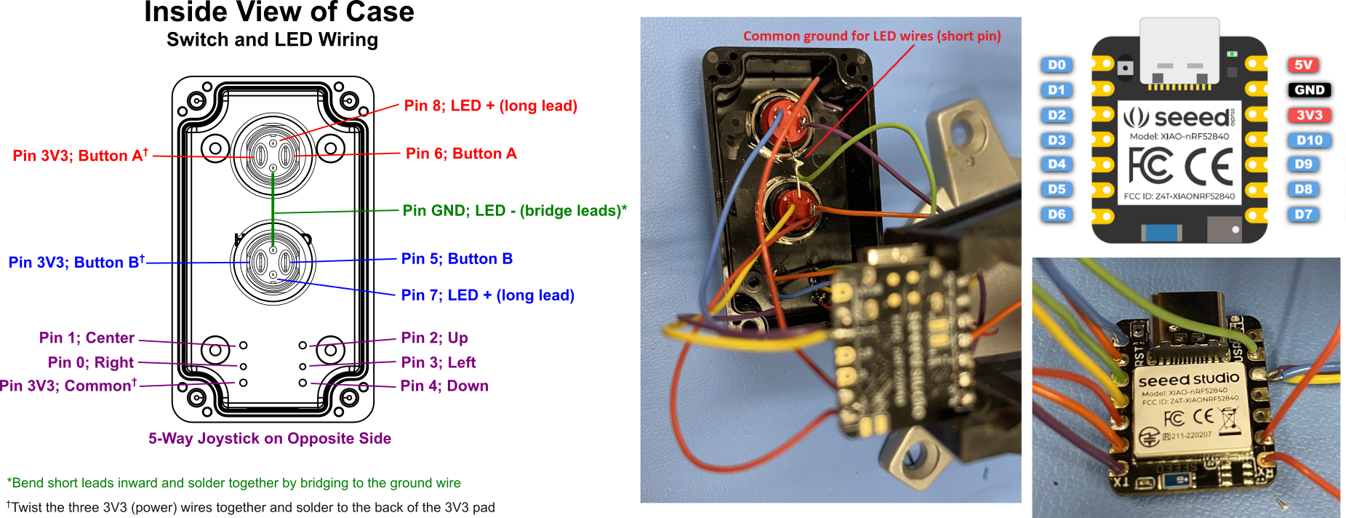
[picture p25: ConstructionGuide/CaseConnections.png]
wiring diagram


You will solder the wires to the pins, which are labeled on the back of the microcontroller, as shown in the diagram. The pinout of the microcontroller, as viewed from the top, is shown in the upper right of the diagram. However, twist the three 3V3 (power) wires together and solder them to the back of the 3V3 pad. The rest of the wires are individually soldered to the indicated pad on the microcontroller.

### Solder 5 Volt Power Cable (Option 1)
If you decided to solder an old USB cable to the microcontroller for power, instead of making a slot for the USB-C connector, you should do this now. As a guide, [see this page](https://www.electroschematics.com/usb-how-things-work/) for the pinout of a USB cable. To identify ground and power, you can plug it in and use a multimeter to see which pin is grounded and which has +5V.

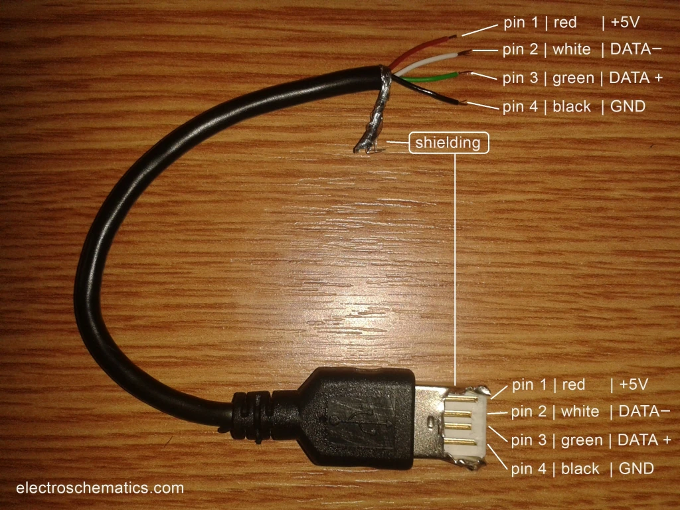
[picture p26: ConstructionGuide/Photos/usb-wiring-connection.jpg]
USB cable pinout


## Install in Case
After soldering all wires, gently bend over the remaining button LED leads such that they do not short to any other pins. Wrap the wires carefully around the buttons in the case as shown below. Press them into the case so that they won't get caught in the case lip when you screw the lid on (otherwise you will pinch your wires and there will be a gap in the lid's waterproof seal).

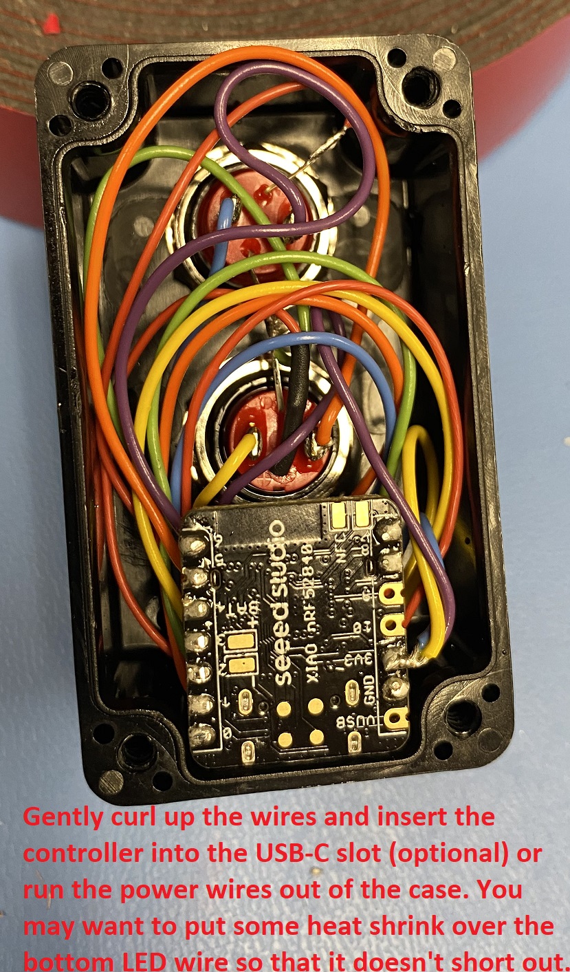
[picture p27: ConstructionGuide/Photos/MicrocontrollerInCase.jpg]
wires wrapped into case


## Upload the Microcontroller Software
The easiest way to do this would be with a custom installer. However, that work is not yet done, so you will need to [download the Arduino IDE](https://www.arduino.cc/en/software), install the support package for the microcontroller, and then upload via a USB cable. The installation steps are [described here.](https://wiki.seeedstudio.com/XIAO_BLE/#getting-started)

First, open the Arduino IDE and then open Preferences in the File menu. Paste the URL (https://files.seeedstudio.com/arduino/package_seeeduino_boards_index.json) to the microcontroller board support package into the "Additional board managers URLs" text field. Click OK. 

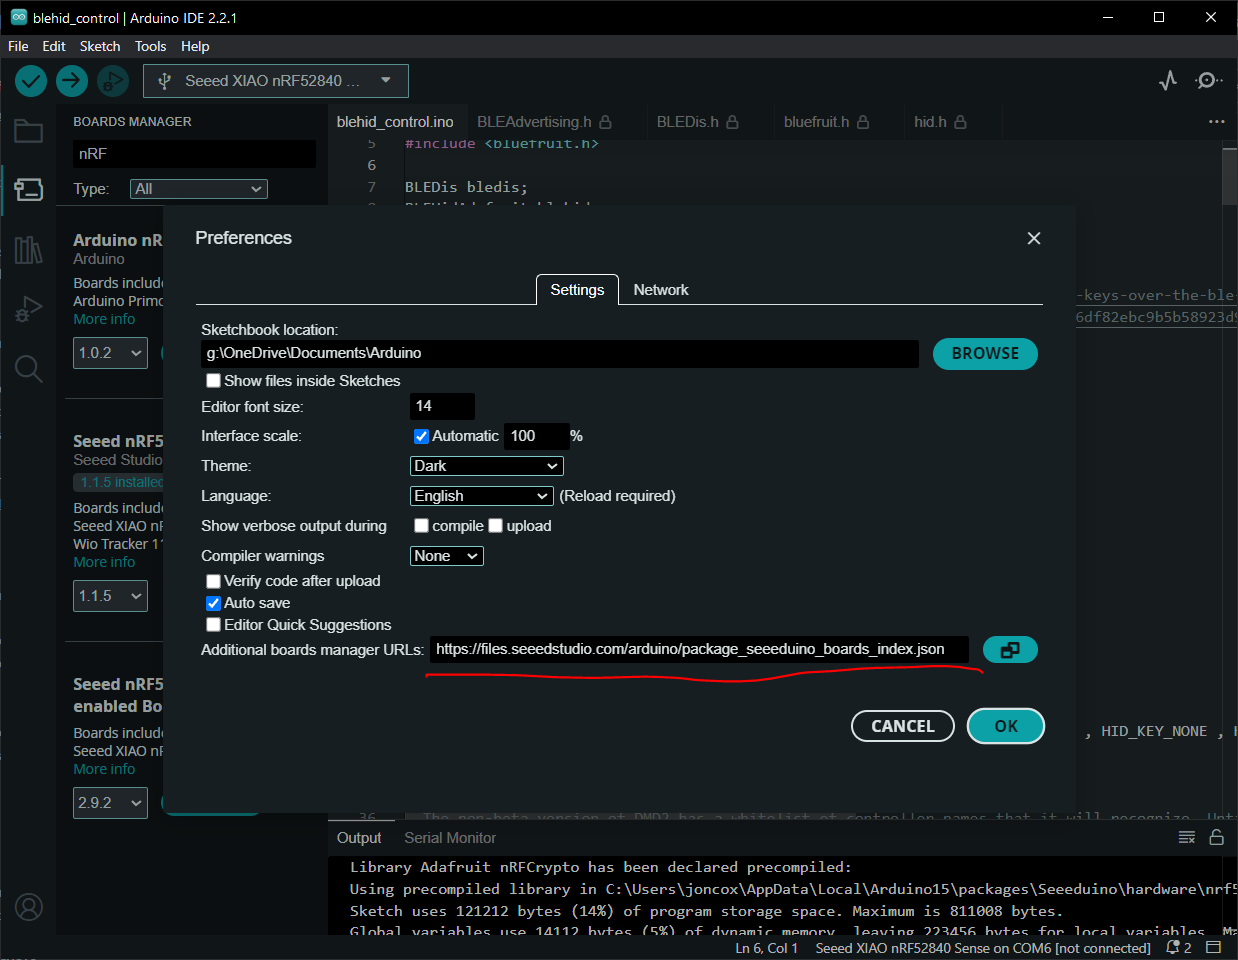
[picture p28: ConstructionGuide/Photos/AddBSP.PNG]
add Seeed BSP


Second, install the Seeed nRF Boards package by clicking on the side button that is second from the top, to open the Board Manager. Type "nRF" into the search field at the top and install the "Seeed nRF52 Boards" package. 

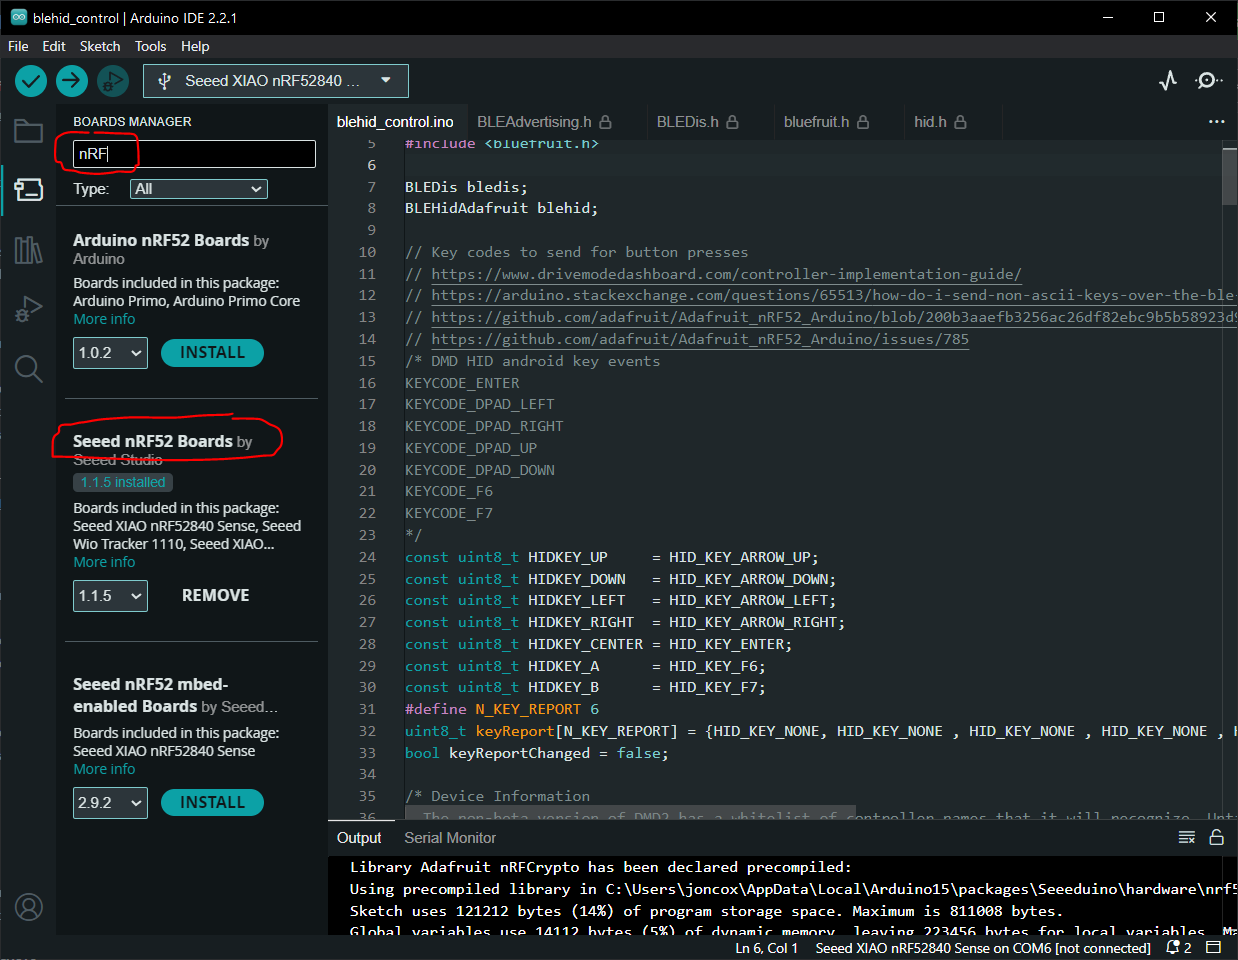
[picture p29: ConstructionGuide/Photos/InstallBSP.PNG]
install Seeed BSP


Third, [download the source code file](../ArduinoCode/MotoButtonsLite.ino) and open in the Arduino IDE. Attach the microcontroller via a USB-C cable. Select the board that you just attached with the drop down box in the upper toolbar. It should say "Seeed XIAO nRF52840".

Finally, click the upload button!

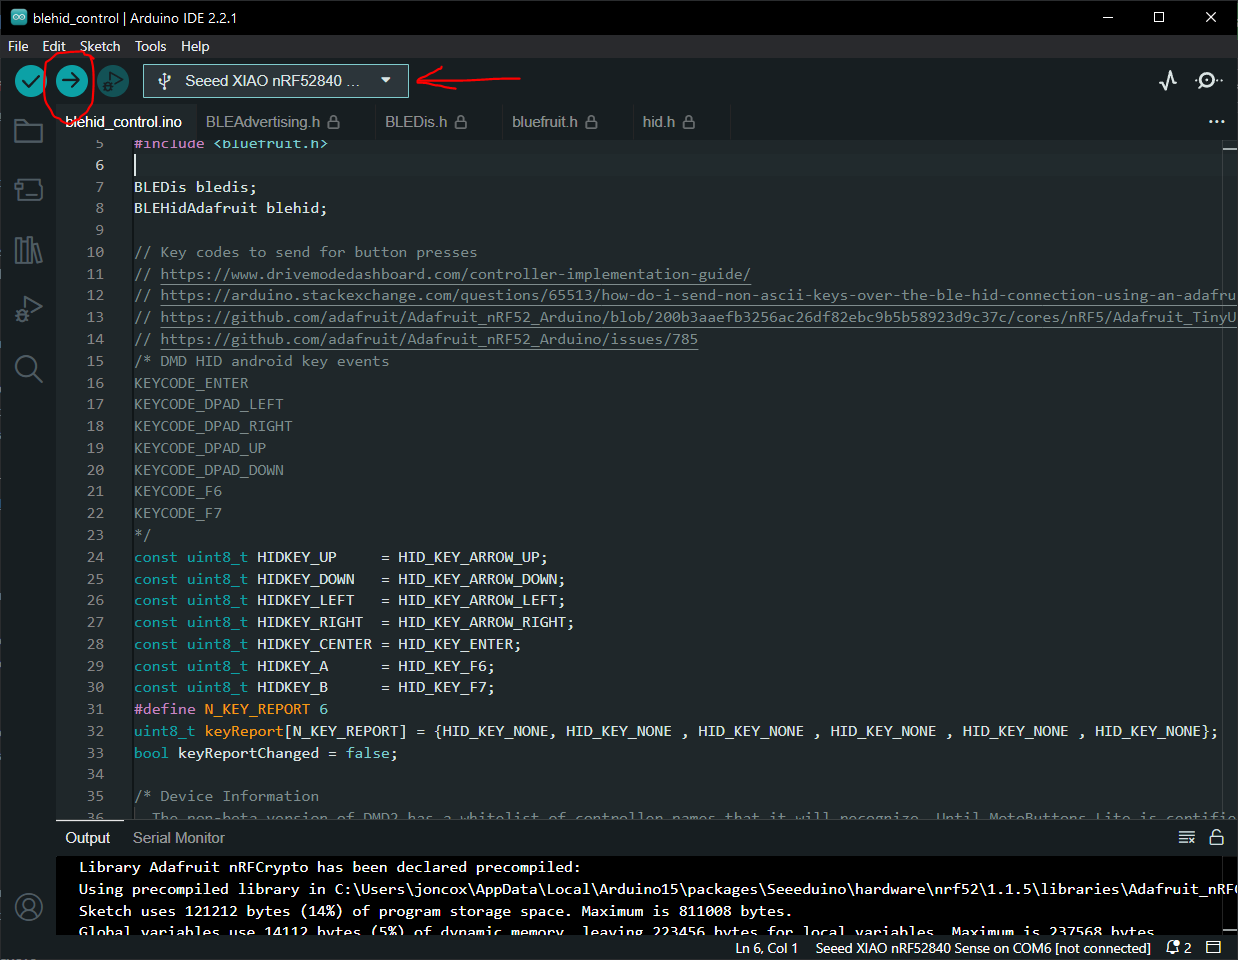
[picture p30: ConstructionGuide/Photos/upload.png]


## Sealing the Case
At this point, you are ready to close the case. However, you have a couple of options to consider before proceeding. Since MotoButtons is currently under active development, you may not want to epoxy fill the case just yet.

Therefore, if you milled a slot for the USB-C connector, I recommend using some hot glue to temporarily seal and fix the microcontroller in the case. If you opted to simply drill a small hole for two power wires (connected to GND and 5V), then you can apply sealant to the power wire holes to make it waterproof, then screw the lid on. 

## Mounting to the Motorcycle
Now that you've completed your build, and hopefully tested it successfully with the DMD2 beta app, you are ready to mount it on the motorcycle. This is the perfect time to be creative and figure out new and better ways to mount the unit. One simple option is to use waterproof, double sided mounting tape to adhere it to the switchgear on the right hand side, for example. You could also adhere it to any other relatively flat surface, including one attached to a RAM ball mount. If you are ambitious, you could attach it to a standard handlebar clamp mount with a screw and bolt or inserting a stud into the case and filling with epoxy. The options are endless.

motobuttons lite installed on handlebar

## Updating the Software for Future Releases
To update the software again, you need to open the case and connect the USB-C port to your computer. Launch the Arduino IDE and open the new source code file. However, there is a bug in the microcontroller's DFU (Device Firmware Update) bootloader that sometimes prevents new software from being uploaded unless a special reset procedure is followed. 

If you try to upload new software and you either get an error stating the DFU upload failed, or it simply times out after about 60 seconds, you probably need to perform the special reset. There are two options to perform this reset. The first option is to hold down buttons A and B for 10 seconds, as if you were changing the mode. This should reset the controller into DFU mode again. The second option is to rapidly double tap the tiny reset button that is next to the USB-C connector. However, this is hard to do because it is so small, and it requires opening the case, which could be impossible if it is filled with epoxy and you can't get to the button. 

After resetting into DFU mode, keep in mind that the COM port (serial port) number of the microcontroller will have changed. So you will need to select it again in the drop down menu in the toolbar at the top of the Arduino IDE. Then you can proceed to upload the new code.

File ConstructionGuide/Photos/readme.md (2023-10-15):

Step by step photos of the construction process.

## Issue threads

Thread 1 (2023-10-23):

Mode Proposal

harupipapaZZZ, 2023-10-23:
Current
DMD Mode
Cursor mode
However,
It would be great to be able to control roadbook operations and apps other than DMD2.
I think barbuttons mode would be helpful.
Navigation, roadbook, and media modes would expand the usage.
Mode status should be indicated by flashing LED's or multi-color LED's, etc.

joncox123, 2023-10-23:
Sure, I can add those additional modes. I'll check it out.

harupipapaZZZ, 2023-10-23:
DMD certified controllers are
Many controllers with DMD certification can be used in modes other than DMD2.
The problem is that if there are too many modes, it is difficult to know the current mode.
In the case of blinking LEDs, constant blinking is too bright, so it is desirable to blink the mode status when a specific button is pressed, or to use color LEDs.

joncox123, 2023-10-23:
That's what a I do currently. Blink when changing modes.

joncox123, 2023-10-25:
Hello, I reworked the code to add support for multiple modes. I also added a mode for MyRoute App. As for mode indication, I now flash the top button LED to indicate the mode number: 1 = DMD2, 2 = mouse, 3 = MyRouteApp. I think this works OK and doesn't require another LED.

I'll look into adding the other modes that you mentioned.

harupipapaZZZ, 2023-10-25:
That's a quick response!

We're also hoping for a version with a waterproof joystick.
I am interested in this

joncox123, 2023-10-25:
The Lite version with the $2.50 joystick is waterproof. But a commercial IP68 rated joystick is about $75 from Digi-Key. I'm pretty happy with this version, actually, so I'm not sure if the commercial IP68 joystick is worth an additional $75. But I did buy a couple IP68 rated switches, so I'll make one anyway.

joncox123, 2023-10-26:
Thinking about modes, it seems there are two main tasks. First, add more long press buttons to support changing media/volume during navigation. Second, add a dedicated media mode and the Rally Navigator mode.

Too many modes will make things confusing, however.

How useful is the WonderLINK mode? I have a 2008 R1200GSA, so I have never used the wonder wheel.

harupipapaZZZ, 2023-10-26:
Long press is good.
Wonderlinq mode for bar button?
That's actually unusable.
I don't know the actual Wonder Link because I don't use it. However, the action of spinning the wheel is actually a pain. I think the operation of JOYSTEICK is convenient.

DMD2 also uses a long press of enter.
This is the DMD2 keycode that I previously found in the Keymapper app. They were also compatible with CARPITER and could be applied to keymaps other than those published.
https://drive.google.com/file/d/1d9zDjYazJbee0ePkRAnInIr7Br5FOKJP/view?usp=sharing

harupipapaZZZ, 2023-10-26:
Since they use the same keymap, you can integrate ROADBOOK mode and media mode.

You can also combine MAPs into one by referencing bar button keycodes and assigning a keymap that can be used by multiple apps.

1.DMD2,
2. MAP,
3. Media & ROADBOOK,
4. Function mode
The above four modes may be good.

joncox123, 2024-02-20:
I have been quite busy at work lately, but I plan to add a media mode and skip waypoint for MyRouteApp. Let me know if there are other ideas.

Joergen57, 2024-02-20:
Hi Jon, you're still alive. ;-)
If you could add something to skip waypoints in MRA that would be fine. Bike session starts soon.
Or if you could give a hint what to change or what to add in the code, that would help as well. I have someone that could change it in the code.

joncox123, 2024-03-05:
media (music) mode has been added as a forth mode. Also, if I read the MyRouteApp instructions correctly, holding down the menu key ("n") for a long time should activate skip waypoint. I haven't tested this since I don't have a MRA subscription, but please give it a try. If it doesn't work, I could add another virtual key for skip waypoint, such as long press of button A or something.

Joergen57, 2024-03-05:
Hi Jon, I am happy that you are back and can follow up.
There are two function for MRA, one needs to be implemented and one needs an update.
Center Joystick one click send a "c" ok is working for center map.
Center Joystick long press send a "n" for menu, but it sends a lot of nnnnnnnnnnnnn that confuse MRA.
What options are possible? Send only one "n" or make a pause for the next on, then you know to release the button?

Next is sending a "d" for skip waypoint. A friend has tried this for me to place in the code. This was set to the first button (A) with long press. Here also it should send only one "d".

I find it also difficult to use the center button from the Joystick, is it may be possible to add "n" as long press to the other button in front (B)?
Is it possible that the buttons are reversed? Means B is in front than A.
I send you the changes we made, dont ask me details, I have no clue about programming. :-(

harupipapaZZZ, 2024-03-07:
Suggestion(1)
Pressing the ENTER button in MRA mode
Is it possible to send the key code ENTER+C+L?

For bar buttons, send ENTER + C + L in sequence.
C = Center Map (Osmand, Kurviger 2, MyRouteApp, etc.). L = Central map/tracking mode change (Guru map). Enter = Center Map (Kurviger 3)
can be made to correspond to

This allows you to move the cursor up/down/left/right on the Android home screen and select apps with the center button, just like in DMD mode.

I set DMD mode to
CENTER = HID_KEY_C; (center of map)
A = HID_KEY_EQUAL; (zoom in)
B = HID_KEY_MINUS; (zoom out)
Virtual = HID_KEY_D; (Menu selection ◀▶)
It has been changed like this,
CENTER =ENTER + C + L
This allows DMD and Osmund to be used in the same mode.

Suggestions (2)
I think you can set it to hold button A and button B in MRA mode.
I don't think it's practical to long press to zoom in or zoom out.

const uint8_t MRA_KEY_UP = HID_KEY_ARROW_UP;
const uint8_t MRA_KEY_DOWN = HID_KEY_ARROW_DOWN;
const uint8_t MRA_KEY_LEFT = HID_KEY_ARROW_LEFT;
const uint8_t MRA_KEY_RIGHT = HID_KEY_ARROW_RIGHT;
const uint8_t MRA_KEY_CENTER = HID_KEY_ENTER + KEY_C + KEY_L;
const uint8_t MRA_KEY_A = HID_KEY_KEYPAD_ADD;
const uint8_t MRA_KEY_B = HID_KEY_MINUS;
const uint8_t MRA_KEY_VIRTUAL = HID_KEY_D;
const uint8_t MRA_KEY_VIRTUAL_A = HID_KEY_N;
const uint8_t MRA_KEY_VIRTUAL_B = HID_USAGE_CONSUMER_PLAY_PAUSE;

If this is it
Can be used in common with DMD, MRA, and Osmund.
Then press and hold the B button to play music.

harupipapaZZZ, 2024-03-07:
I made a mistake.
const uint8_t MRA_KEY_A = HID_KEY_EQUAL;
MRA needed to expand.
Then DMD, OSMAND, and MRA can be used in common.

Joergen57, 2024-03-07:
Hi, two things I noticed in MRA mode.
1. long press center to open menu is difficult to find right timing, because menu close very quickly.
2. long press A button (zoom minus) to get a "d" for skip waypoint forces MRA first to zoom out and then skip waypoint.*

*This belongs to the changes I made (see above).

It would be nice if the zoom buttons in/out +/- only send one command by pressing, so one + and one - not endless until you release button.

Joergen57, 2024-03-07:
I am not sure. Yes, skip waypoint seems to be more important than the menu. I like more the A/B buttons, then the center joystick button, I think it is not good with gloves.

And, yes I sometimes need the menu.

harupipapaZZZ, 2024-03-09:
Press ENTER button in MRA mode
Is it possible to send the key code ENTER+C+L?

I tried using keymapper

However, it didn't work as expected.
When you press CENTER, the C+L key code is sent first, so the characters are entered into Google search and it doesn't work as expected.

Maybe using send when key is pressed and send when key is released might work, but I can't test it.

A simple solution is
It is necessary to set the A button and B button to be held down.
Make settings as below

const uint8_t MRA_KEY_UP = HID_KEY_ARROW_UP;
const uint8_t MRA_KEY_DOWN = HID_KEY_ARROW_DOWN;
const uint8_t MRA_KEY_LEFT = HID_KEY_ARROW_LEFT;
const uint8_t MRA_KEY_RIGHT = HID_KEY_ARROW_RIGHT;
const uint8_t MRA_KEY_CENTER = HID_KEY_ENTER
const uint8_t MRA_KEY_A = HID_KEY_EQUAL;
const uint8_t MRA_KEY_B = HID_KEY_MINUS;
const uint8_t MRA_KEY_VIRTUAL = HID_KEY_D;
<Add>
const uint8_t MRA_KEY_VIRTUAL_A = HID_KEY_N;
const uint8_t MRA_KEY_VIRTUAL_B = HID_KEY_C;

I can't try it because I don't have the skills to change the program, but
You should now be able to control DMD, OSMAND, MRA, and the Android home screen.

and with that
MRA mode
It might be best to set the A, B, and middle buttons to not repeat. Virtual too

harupipapaZZZ, 2024-03-31:
<Add long press>

MRA mode
Long press A button HID_KEY_N
Long press B button HID_KEY_C

<How to change mode>
Press and hold the A and B buttons at the same time for more than 1 second
Becomes “mode change acceptance state”

1) The ”mode change acceptance state” lasts for a maximum of 10 seconds.
2) If the UP button is pressed in the "mode change acceptance state", the mode changes to DMD2 mode and the "mode change acceptance state" ends.
3) If the LEFT button is pressed in the "mode change acceptance state", the mode changes to MRA mode and the "mode change acceptance state" ends.
4) If the DOWN button is pressed in the "mode change acceptance state", the mode changes to MUSIC mode and the "mode change acceptance state" ends.
5) If the RIGHT button is pressed in the "mode change acceptance state", the mode changes to MOUSE mode and the "mode change acceptance state" ends.
6) If the A button, B button, or C button is pressed in the "mode change acceptance state", the "mode change acceptance state" ends.
7) If no button is pressed during the "mode change acceptance state", the "mode change acceptance state" ends after 10 seconds.
8) Display the current mode on the LED after changing the mode (current and unchanged)

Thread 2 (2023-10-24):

USB-c port

pmfrey, 2023-10-24:
Am I missing it or is there a link to find a usb-c port if you want to use that?

joncox123, 2023-10-24:
Sorry, do you mean a USB-C cable?

pmfrey, 2023-10-24:
I don't think so, but maybe I misunderstood the build instructions. I meant usb-c female port to build into the controller. or is that built into the seed bluetooth controller part?

joncox123, 2023-10-25:
No, you don't need to buy a USB-C port, that is already soldered onto the microcontroller.

joncox123, 2023-10-25:
Issue resolved

Closed 2023-10-25.

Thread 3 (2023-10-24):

Additional Mode

Joergen57, 2023-10-24:
Hi Jon,

thanks for the project. I ordered the parts and cant wait to test is with my Oukitel Android tablet, I am using MyRouteApp (MRA) for navigation and hope that the Motobuttons work with MRA as well. MRA will support BarButtons, WunderLINQ and SilverFox, but these are more expensive. As suggested in another issue, BarButtons mode would be nice to have as well.
If it works with MRA, there will be a lot of request, for this controller. I will let you know.
Is there a plan to offer final products for none DIY people?
PS: I send you a message via FB, you can ignore it.
Regards
Jörgen

joncox123, 2023-10-24:
I will look into MRA and add support if possible. The only challenge would be if MRA has a whitelist of controllers like the DMD2 non-beta app does.

joncox123, 2023-10-25:
Hi Jorgen, I researched adding support for MyRoute app. It will be easy to do. The key mapping uses up/down/left/right arrows, like DMD2, but also 'c' (center), +/- (zoom in/out), and 'n' to activate the menu. Since Motobuttons Lite only has 7 total buttons, my idea is for 'n' to be sent via a long press of one of the other buttons.

joncox123, 2023-10-25:
Hello, I reworked the code to support multiple modes, including a mode for MRA. I also made many other improvements. Please give it a try with MRA and let me know if you have suggetions. I will also test it out, but it seems to work OK.

Joergen57, 2023-10-25:
Hi, you read my suggestion, and you have it already implemented.

That is great, thank you very much. 👍

My parts will arrive tomorrow and I hope I can finish the MotoButtons over the weekend. I will let you know the result.

joncox123, 2023-10-25:
By the way, there is a bug in the microcontroller that requires double tapping the tiny reset button to put it in software upload mode. Therefore, make sure you can access the top of the microcontroller to reset it after you complete construction.

Also, as a result, I'm not sure it makes sense to mill a slot for the USB C port. It's better to drill a hole for a USB cable to provide power. Just make sure it's long enough in the case that you can reset the microcontroller to update.

Joergen57, 2023-10-25:
Hi, yes, I read this already. Do you think it is possible to turn the PCB around to get to the reset button? Will it fit then?
Maybe a hole in bottom gives access to reset.
I will take a look when the parts arrive.

joncox123, 2023-10-25:
Yes, it would be better to solder the wires from the opposite side so that the top of the microcontroller faces out from the enclosure.

joncox123, 2023-10-25:
Hello, I believe I found a solution for the software update bug. There is a function, enterSerialDfu() which calls NVIC_SystemReset() after setting the bootloader to Device Firmware Update (DFU) mode. This seems to work to reset the device to allow new software to be uploaded without requiring you to open the case and hit the world's smallest reset button twice.

Therefore, assuming this is reliable, what you can do to update the software is to hold down both buttons A and B (as if you were changing the mode) for 5 seconds. This will immediately reset the microcontroller and should allow you to upload firmware. No need to open the case or touch the microcontroller.

joncox123, 2023-10-25:
Haha, if your helmet hits both buttons for 10 seconds during a hard brake, you have bigger worries than a $28 device! However, I  don't think its possible to accidentally hold down both buttons for 10 seconds. But this could be increased to 30 seconds, for example.

Joergen57, 2023-10-26:
No, no, during a brake I sometimes place the helmet over the mirror. If the switch close to that...

Joergen57, 2023-10-27:
Some questions (I started the build). Power supply can be via the USB-C Port or an attached cable?
Do you know the power consumption of the circuit?
I think about a battery (maybe with switch)
Is it necessary to reconnect the BT after power of?
Thanks

joncox123, 2023-10-27:
The MCU has a built in battery manager circuit with dedicated battery pads and charging circuit. I don't know the power consumption, but the software isn't designed for saving power.

Bluetooth automatically reconnects within a few seconds with my Android OnePlus 5 phone.

You can power the MCU via either 5V to the pad or a USB-C cable in the USB port. I think soldering an old USB cable 5V wire to the 5V pad is the easiest way to build and waterproof the enclosure.

The 3V3 pad is NOT a power input.

Joergen57, 2023-10-27:
Thanks for the answer, I understand.

[diagram.pdf](https://github.com/joncox123/MotoButtons/files/13191037/diagram.pdf)

Maybe useful, helps me to attach the wires. Fell free to use it.

joncox123, 2023-10-28:
Thanks, nice diagram. Let me know what you think of the current software. I have some work to do this weekend, so I won't have much time to work on it until next week. However,  I think it needs multimedia functions (volume, change track) and a bit more work on the button logic with respect to preventing spurious key presses when changing modes.

Closed 2023-10-25.

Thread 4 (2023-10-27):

Seeeduino XIAO ESP32C3

harupipapaZZZ, 2023-10-27:
Seeeduino XIAO ESP32C3
This is a. WI-FI and blutooth 5.0 are available.
WI-FI is available for OTA updates during development.

Half the price of the Seeed Studio XIAO nRF52840

I haven't used it yet, but there seem to be some caveats.
https://wiki.seeedstudio.com/XIAO_ESP32C3_Getting_Started/

I'm not familiar with programming, but if I use this, do I need to change the wiring or code?

joncox123, 2023-10-27:
Yes, the code will be completely different and will need to be rewritten. But that's a good find, I'm not sure why I didn't see that model. I might order one and test it out.

Closed 2023-11-01.

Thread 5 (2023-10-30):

Need help it is not working

Joergen57, 2023-10-30:
Hi, I finished the build installed the software and code and it seems all ok, but the controler does nothing.
I disconnect the controller from power and reconnect more then ons. No LED flashing, I checked LED function and wireing, it is ok.
I am totally new regarding programing and Arduino. I hope I followed the instructions correctly.
From screenshot  I think it looks ok.

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

There is no Bluetooth to see.  So what would be the next step to find the problem?

Joergen57, 2023-10-30:
HI, I have no idea what happen, I went through the tools menu and clicked monitor and suddenly the LEDs starts flashing. I can connect now via BT and controller is working. Big ? what happend.
So can be closed for now.

joncox123, 2023-10-30:
It looks like it programmed OK. Check with a multimeter that you are getting 5 V between the 5V and GND pins on the microcontroller. I think you must have a power or wiring issue. Check that you didn't reverse the LED connection, those have a polarity.

Joergen57, 2023-10-30:
OK, I could limit the problem a bit. It is not working with a power bank connected via USB-C. I tried two different ones. It works only with a USB-Cable connected to a PC. May be an additional signal is needed what a power bank can not supply. The power consumption is lower then 0.00 A.

Another problem found, it works only at the PC where Arduino IDE is runing, not at another PC USB connector.
When I close Arduino IDE at the working PC it still works, but when I reconnect it does not.
Starting Arduino IDE again then it is working agin.
Very strange?
May be I need to attached 5V via extra USB-cable wired to PCB.

Joergen57, 2023-10-30:
So it is not a power bank problem.

Joergen57, 2023-10-30:
So, direct attached 5V does not change anything, still not working. I checked 5V on the Board, it is available, by external power and/or USB-C power, same for the 3.3V it is there at both.

joncox123, 2023-10-30:
I will run a few tests today and let you know what I find. But it seems like it might be a wiring issue. Make sure that nothing can short out. Also, check wiring and LED polarity.

joncox123, 2023-10-30:
Ok, I think I know what the problem may be. The code is probably waiting for a USB serial port connection when it starts up. Thus, I probably need to modify the source code so that it does not do that. I will t st that out in about an hour and upload new code if it fixes it.

joncox123, 2023-10-30:
Hi, I fixed the problem. The code was indeed waiting for the connection of a USB serial port. That is why it was not working when not attached to a PC. I tested it from a USB charger, and it is working OK. I will close this for now, but open a new issue if you have another problem. Thank you

joncox123, 2023-10-30:
Also, please upload the latest source code version, v1.1.1, using the Arduino IDE. After that, the problem should not reoccur.

Joergen57, 2023-10-30:
Thanks for the quick reaction and help to fix it.
The new code looks a bit strange and it includes my Mail address? Please delete this!

joncox123, 2023-10-30:
No, it does not have your mail address. Where are you seeing this?

Joergen57, 2023-10-30:
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

Joergen57, 2023-10-30:
something went wrong with the download I gues

joncox123, 2023-10-30:
I think you downloaded the entire web page instead of just the code. Try downloading only the code or copy and paste it into the IDE.

Joergen57, 2023-10-30:
Seems a mistake on my site, sorry. (absolute beginner)  ;-)
So looks good, runs now with power bank and a blue LED is blinking at (i guess) boot.

Joergen57, 2023-10-30:
Where can I make suggestions, here under issues?

joncox123, 2023-10-30:
Yes, open a new issue for a suggestion.

Closed 2023-10-30.

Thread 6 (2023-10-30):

Suggestion

Joergen57, 2023-10-30:
Hi Jon, first of all thank you for the great project. This is exactly what I was looking for and that you implemented MyRoute-App support is really great.
I love DIY projects and because of the very detailed instructions I was able to build the whole thing as a complete beginner.
And thanks again for the troubleshooting, now it works.
I would like to make two suggestions.
1. it looks like the Motobuttons consumes almost no power, then it would not be bad to use a battery. The board seems to be prepared for this.
2. at the moment the joystick is laid out so that the two switches are above. It would not be bad to be able to use the whole thing the other way around, or even sideways. So that the switches are sometimes below or (right / left) of joystick. You could do this by changing the cables from the joystick, but that is surely also possible by changing the software, right?
Nothing important, just my first thoughts:
A praxis test on the bike with the controller and MyRoute-App will follow.

joncox123, 2023-10-30:
Thanks for the suggestions. Battery power could be a possibility if current consumption is not too high. I'd have to measure this.

As for rotation of the button layout, I agree, this is something I had planned to do. I realized that you want the power cable running toward the front of the motorcycle.

Layout rotation can be easily accomplished in software, although a question is whether it is better to set the mode in the source code or allow the user to change it dynamically on the motorcycle. I don't want the modes to get too complicated or it will be hard too use.

Editing one line in the source code wouldn't be too hard, right? Just change: const int LAYOUT UP to const int LAYOUT DOWN, for example.

joncox123, 2023-10-30:
OK, I have an idea for how to rotate the layout dynamically. When the device is powered up, it checks whether one of the joystick directional buttons is held down. If so, it sets the direction to be up. It stores the setting and automatically applies it the next time it is powered up.

Joergen57, 2023-10-30:
Battery power could be a possibility if current consumption is not too high. I'd have to measure this. **My USB power meter is not showing any current (it starst at 0.00 Amps) so it must be below 9mA.**

As for rotation of the button layout, I agree, this is something I had planned to do. I realized that you want the power cable running toward the front of the motorcycle. **Correct!**

Editing one line in the source code wouldn't be too hard, right? Just change: const int LAYOUT UP to const int LAYOUT DOWN, for example. **That should be possible to change with an editor.**

joncox123, 2023-10-30:
Hi, I added the functionality to rotate the orientation of the buttons. This is done by holding down the "up" direction that you want on the joystick when applying power. The change is stored in memory for the next power cycle.

Joergen57, 2023-10-30:
Wow, you are so quick.

To overwrite a setting you just hold the joystick up again?

joncox123, 2023-10-30:
Well, I have been out sick and couldn't sleep well last night, so I have been working on this to pass some time.

But yes, you hold down the new "up" direction that you desire while powering on. Then it will set the new orientation and save it for the next power on.

Joergen57, 2023-10-31:
Hi, I just tried to install the new version and got an error:

_Possible causes:
- Selected Bootloader version does not match the one on Bluefruit device.
    Please upgrade the Bootloader or select correct version in Tools->Bootloader.
- Baud rate must be 115200, Flow control must be off.
- Target is not in DFU mode. Ground DFU pin and RESET and release both to enter DFU mode._

Is this the problem with reset button?

joncox123, 2023-10-31:
yes, hold down the two buttons for 15 seconds until the COM port changes. Select the new port in the IDE and upload again.

Joergen57, 2023-10-31:
Great, thank you! (Thumb up) I got it!

By the way, I have difficulties with the center button from the joystick, it is not easy to press it without making an up, down, etc.
I think about another button as replacement for the center.
The joystick is working fine.

joncox123, 2023-10-31:
The center button can be improved with software.

Joergen57, 2023-10-31:
The long press is the main problem, it could happen that MyRouteApp went into an unknown mode where you can only stop and restart the App.

joncox123, 2023-10-31:
I implemented a feature that drastically improves that problem. The solution is to disable up/down/left/right whenever the center is depressed. I think more can be done, however.

joncox123, 2023-11-01:
Hi, please try the new version, v1.2.1. This includes the improvements to center button usability. I also fixed an issue where it was repeating the center click. I think it works much better, please let me know if you still have problems with it.

Joergen57, 2023-11-01:
Hi, I did a quick test ( I will a tour today). It looks like the button reaction is better. I only have the problem in MRA in BarButton mode how to get out of a menu? No button helps, I need to tap the screen. A left or right with the joystick could help. I am not sure if this barbutton conform. Or how they foot. May be with another button. May be I get some info in the forum. But tonight.

Joergen57, 2023-11-01:
At first, I ask some questions to the MRA developer.

@Corjan-Meijerink I build the MotoButtons and they work fine so far. The author made some changes already to improve the function.
But they are not perfect, or may be I did something wrong.
The MotoButtons are in BarButton mode as well as MRA. Moving map, zoom in out are ok, long press on the joystick Center open menu or Center map. If I am in the menu, I can move up down, but how to get out of the menu? What command is needed, or how does the BarButton do this? With another button? And how is the skip waypoint working, also with another button? May be a BarButton owner can help.

Next, there still something wrong with the joystick Center, I am not sure how to describe and if it is a button problem?

If you hit the Center button you change the view mode of the map. (Navigation view, 2D view etc.) With long press you change into total overview. Longer press opens menu, but here is the question how to get out of the menu.
There is one thing that also need a solution, the skip Waypoint function.
In the App you can tap on the waypoint sign (right up) to get a skip waypoint window where you need to confirm this. Or you press longer to skip the WP directly.
I fear Motobutton needs more buttons. ;-)

joncox123, 2023-11-01:
There are a few ways to handle this. Probably it's best if the long press for menu is shared with one of the large buttons. I think that should fix it.

joncox123, 2023-11-02:
Another thing is that DMD2 and MyRoute App handle button presses differently. DMD2 ignores key repeat, while MRA will see Android's internal key repeat presses.

I don't have an MRA subscription, so it's hard to test all of the features, but it seems like I can change the button functionality a bit to solve the problem.

I can make it so the A B buttons only fire once per press (not necessary with DMD2). Also, the long press for menu could be changed to a long press of the B button.

I think that will fix it.
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
Joergen57, 2023-11-04:
No, neither 100 nor 250 delay makes a change. I will add a different/additional button tomorrow for the center button, just for testing
I find it difficult to hit the center (only) without touching a left/right/up/down button, So may be the button has a problem or this kind of double signal.
It's a shame that it doesn't work so easily and that you have so much work with it, but thanks for it anyway.
I will continue tomorrow and follow your instructions.

joncox123, 2023-11-04:
I highly suspect it is a locale issue. Try the log test that I posted above. This will tell us for sure.

joncox123, 2023-11-04:
Also, do the log test before making any hardware changes.

Joergen57, 2023-11-04:
How to sent (Send me the log from KeyEventDisplay.)?

joncox123, 2023-11-04:
I tested the controller on my Android phone after setting the "keyboard layout" to German using the Android Settings. In this mode, the + key gets translated to "/" by the Android operating system. The other keys work correctly. Therefore, it is certain now that the "keyboard layout" for the controller must be set to US English in Android and iPhone settings to work correctly.

See instructions here for Android: https://www.mobilefun.co.uk/blog/2015/04/how-to-fix-bluetooth-keyboard-language-settings/

Also, are you using German layout on both of your phones, or is the Android different (maybe Dutch or something else)?

Lastly, I can't save a log from KeyEventDisplay app either. Instead, you can send me a screenshot. I just need to see the "action=0 code=XXX" part of each line.

Joergen57, 2023-11-05:
So, just a short one (familie is waiting) ;-)
I played back Version 1.2.2  and checked with keyboard layout English (USA) and English (USA) international.
No change. If I press longer then 2 sec. or do not stop pressure on center MRA hangs with black screen.
By exident google opens and I could see what the key did in text editor.
Longpress Center 2 sec. = n
Short press = c
Zoom + = +
Zoom - = -
Longpress Center > 2 sec. = nnnnnnnnnn
The above result was the same with **USA keyboard layout or NOT**
If you know to stop pressing when the LED is flashing you always jump into the menu.

What I still not know is how to get out of the menu?

I will do later today the keyboard log, but I belive I will get the same result.

Joergen57, 2023-11-05:
Just had an Idea, and installed BT keyboard the tablet.
I could move the map with the arrow keys.
I could not zoom in/out with +/-
I could use c to change between 2D/3D mode
I could use n to open and close menu

And if I press n longer MRA hangs with black screen, so first not a MotoButton issue. But some questions.
Why does +/- not working?
Why can I close menu, when I press again?
And why hangs MRA by pressing n longer?  (that is something for Corjan)

joncox123, 2023-11-05:
Based on your log result, it is working correctly. Key repeat is handled internally by Android and iOS, and it is working correctly for me on both iOS and Android with MRA.

MRA isn't supposed to crash because you hold down the n key a little too long.

The problem is with your version of Android and MRA causing a crash due to not handling key repeat correctly. I think this is clearly an usual MRA bug.

A work around for your case could be to force the firmware to send a key release event immediately after sending the center key down event. But this is something that is supposed to be handled by MRA and Android. So it would be a hack intended to address an MRA bug specific to your situation.

However, the best solution in your case is to try turning off key repeat in your Android using an app: https://amigotechnotes.wordpress.com/2019/01/24/android-repeating-keys-with-an-external-bluetooth-keyboard/

https://play.google.com/store/apps/details?id=com.apedroid.hwkeyboardhelper

Joergen57, 2023-11-05:
Hi Jon,
In principle, you are right, the controller works correctly.
If you keep the timing. It seems to be a problem with MRA if you hold down the n key a little too long, the App crashes.

Do you think a key events logging is still needed? I don't think so, or?
And, can the MRA developer improve something? I will report this anyway.

Thank you for your support and your patience.

Closed 2023-11-05.

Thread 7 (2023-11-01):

Suggestion

ConTS10, 2023-11-01:
I like this project very much, but I hate the smudgy look of the sealing method. Would it be an idea to stick the joystick through a round hole from the inside of the box, and press it, with the rubber boot in between, against the outer wall by a constructed bridge from the inside? I might think up a 3d-printed case over the winter that does exactly this. The result is also that the stick does not stick out that much.

joncox123, 2023-11-01:
That won't work, but it's possible to use your finger to smooth the silicone sealant better. The project is mainly about price over appearance. For a nice appearance, there are many commercial options for $250 to $300.

Closed 2023-11-01.

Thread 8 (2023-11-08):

Request for additional button

Joergen57, 2023-11-08:
Hi Jon,

is it possible to add the code for an additional button?
I am missing a button in MRA with "BarButton mode" to skip waypoints. It is made with "d".
From the Hardware site it should be possible (two pins are free on the board).

joncox123, 2023-11-09:
This could be added as another long press of one of the larger buttons. I wasn't aware of the d key function.

It's certainly possible, but it has to be done with care because it gets a little tricky to implement the long press correctly.

Joergen57, 2023-11-09:
If you could think about it, it would be nice. Nothing urgent, motorbike season is over anyway.
Take a look here: https://jaxeadv.com/barbuttons/compatible-applications/#htoc-m under MRA.
Yes, long press on one of the buttons could be an option.

harupipapaZZZ, 2023-11-11:
You may want to refer here.
https://jaxeadv.com/barbuttons/using-the-barbuttons/barbuttons-user-guide-v4/#htoc-keymap-4-custom11111

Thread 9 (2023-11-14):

Change button parts

harupipapaZZZ, 2023-11-14:
The current button is a button switch with LED, can I change it to a normal button (tact switch without LED)?
This is because the LED is not visible when you press the button and is cheaper to manufacture than using a button with an LED.

Can I use two regular LEDs and connect "LED_BUTTON_A", "LED_BUTTON_B" and "GND"?

Do I need to change the source code?

I am wondering if it is possible to use a thin tact switch instead of the specified waterproof LED button.
The main body BOX can also be made thinner.
(Isn't one LED actually enough?)

Joergen57, 2023-11-15:
I belive this is possible and no need two change the code.

harupipapaZZZ, 2023-11-15:
thank you

There was a long wait for the parts I ordered from MONSTER due to export procedures. It will finally arrive tomorrow.

When the parts arrive, I will try to make a temporary connection to check the operation.

Joergen57, 2023-11-15:
My first version is working. I recommend reading all issues.
What will be the usage for your MotoButtons?
I will use it for MyRoute-App.

harupipapaZZZ, 2023-11-18:
It is still a prototype,
Smaller with tact buttons and joystick

There are no waterproof caps for tact buttons on the market, so I made a mold out of silicon.

https://github.com/joncox123/MotoButtons/assets/129697360/59f4436a-33fb-49c7-8fb6-362684c84435

Joergen57, 2023-11-18:
Cool, I like the tiny buttons. What buttons are this exactly? And did you do the silicon covers?

harupipapaZZZ, 2023-11-18:
ALPS tactswitch "SKRGAED010"

Based on this, we made a 3D drawing covering the entire switch and
Print it with a 3D printer (UV curing for precision)

Put the finished product in a mold to create a silicon mold (top and bottom)
Then pour the silicon into the mold and shape it.
It takes a tremendous amount of time and effort.

This is a leftover from a previous project.

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

harupipapaZZZ, 2023-11-18:
Since there are two LEDs, they take up a lot of space.
It would be nice to have only one LED because it would make the design more compact.

Currently designing a vertically aligned body
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

Joergen57, 2023-11-19:
I am not sure what the second LED is for. I know the LED on Zoom + indicates the 3 modes. May be Jon can answer this.

joncox123, 2024-02-20:
Hi, I've been quite busy at work, but I plan to revisit development soon. I agree, the LED buttons are a pain because you can't see the light when you press the switch. Since the LED is just a separate set of terminals, you can use different buttons and easily wire up a separate LED somewhere else.

lostinalps, 2024-02-20:
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

Where did you find the joystick? Is it waterproof?

Closed 2024-03-07.

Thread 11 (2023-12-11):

Using a battery for Motobuttons

pmfrey, 2023-12-11:
Hi would you give some advice on what type of battery you would use if you wanted motobuttons to run without the USB connections. It would make it easier to swap between different bikes. Thanks. Peter

joncox123, 2024-02-20:
The microcontroller actually supports a battery, I believe it has a lithium ion controller built in. You would want to solder a small 3.7V lithium polymer battery to the BAT +/- pads.  Please read the Seeed docs for the microcontroller for more info.

Closed 2024-02-20.

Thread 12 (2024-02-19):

I tried  it.

harupipapaZZZ, 2024-02-19:
I tried  it.

I tried changing the DMD code.

The original is

const uint8_t DMD_KEY_CENTER = HID_KEY_ENTER;
const uint8_t DMD_KEY_A = HID_KEY_F5;
const uint8_t DMD_KEY_B = HID_KEY_F6;
const uint8_t DMD_KEY_VIRTUAL = HID_KEY_F7;

but,

CENTER = HID_KEY_ENTER;
A = HID_KEY_F6
B = HID_KEY_ESCAPE;
VIRTUAL = HID_KEY_D;

Changed to
In MAP mode
A button = shortpress: zoom in (Longpress:hotomap)
B button=shortpress: zoom Out(Longpress:displayLock)
Center button = shortpress: Enter(Longpress:menu select◀▶)
It has become easier to use.

It would be useful to have a button to play music while driving and a way to specify the next song, previous song, volume up, and volume down.

But I couldn't find the code to change it.
If anyone knows please let me know.

joncox123, 2024-02-20:
I think the solution is to add a media mode specifically for controlling the media functions in the phone, such as play track, next track, etc. This is on the to do list. I've been quite busy at work the past couple of months, but I should have some time soon.

harupipapaZZZ, 2024-02-20:
It is a very good project and I am looking forward to it.

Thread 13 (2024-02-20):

Suggestions for additional functions

harupipapaZZZ, 2024-02-20:
1) Display current mode
It is difficult to see the current mode when using the system.
It would be good if it could be indicated by a color change in the color LED or by the number of times the LED blinks during certain operations.

2) Use a different LED from the one attached to the button.
And change to a single LED.

3)Mode change operation with a single finger
Simultaneous pressing of two buttons cannot be done with one finger.
Therefore, it is easier to operate if mode can be changed with a specific action.

4) The current joystick is small and very convenient to put a waterproof cap on it.
Since I cannot find normal tact switches with waterproof caps on the market,
Use this joystick (with waterproof cap) and use it instead of a button.
The small size allows for a smaller case.

For example
Joystick A (center & up/down/left/right)
Joystick B (center & up/down/left/right)
This allows 10 buttons to be operated.

The maximum number of buttons supported by DMD is 8, but actually there are other code assignments than F 5, F 6, and F7, so only the name should be DMD2 CTL 8K and it will work!
If you do this I am available for consultation.

razorbac91, 2024-03-01:
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

I tried last week to program a super simple blekeyboard with an ESP32C3 super mini, but I can't make it working. It connect fine but doesn't output anything, same code on a D1 esp32, works flawless

joncox123, 2024-03-05:
media (music) mode has been added as the forth mode

harupipapaZZZ, 2024-03-07:
Confirmed thank you

Closed 2024-03-07.

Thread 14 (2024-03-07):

Suggestions for mode change behavior

harupipapaZZZ, 2024-03-07:
You can change the current mode by pressing and releasing Button A and Button B at the same time.

If you perform this action
Change in the order of mouse → DMD → MRA → MEDIA,
When changing from DMD to MEDIA, you need to change the mode twice.
When the LED flashes during the day, you won't know which mode you're in because you can't see the light.

Proposal (1)
How to select the mode

Is it possible to press and hold the A and B buttons to enter the mode change acceptance state, and then press the direction button to select the mode?
top = mouse
Left = DMD
Right = MRA
bottom = media
This allows you to change directly to your desired mode.

Proposal (2)
Change mode change behavior

The action of pressing the A and B buttons at the same time with one finger is difficult, so

for example,
A quick press of left, right, A, and B starts the mode change operation, which can be operated with one finger.
after that
top = mouse
Left = DMD
Right = MRA
bottom = media
Press to select the mode.

Pressing left, right, A, and B quickly in sequence is not realistic for operating DMD or MAP, so I don't think it will malfunction.

addition
If the number of modes increases beyond 4, add a mode change operation.
If you quickly press up, down, A, and B in order

Top = mode 5
Left = mode 6
Right = mode 7
Down = mode 8

Changing modes in the current order is cumbersome.
This allows you to easily change to your desired mode.

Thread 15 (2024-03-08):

Change suggestion media mode

harupipapaZZZ, 2024-03-08:
Change suggestion media mode
(1)
Many controllers have a media mode that allows you to operate the Rally Roadbook Reader app.
How this app works

Volume UP = Trip meter up
Volume DOWN = Trip meter down
Previous track = Scroll up the roadbook
Next track = scroll down the roadbook
It will be.

With the current settings, you will make a mistake when trying to scroll down the roadbook while driving in the roadbook rally.
(This will cause the trip meter value to change inadvertently.)

The improvement is
MEDIA_KEY_UP = previous song
MEDIA_KEY_DOWN = next song
MEDIA_KEY_LEFT = Mute
MEDIA_KEY_RIGHT = stop music
MEDIA_KEY_CENTER = play - pause
MEDIA_KEY_A = volume up
MEDIA_KEY_B = volume down

By doing so, there will be fewer erroneous operations.

(2)
This is a very important point.
The current media mode only sends the key once when you press the button.
This requires multiple button presses when operating the trip meter or roadbook.
It is very troublesome to correct the distance on the trip meter. It takes hundreds of presses to correct.

The improvement is
Please set all buttons to hold down and repeat the key code when pressed for a long time.
Then, with a short press, you can fine-tune the trip. You can move continuously by pressing and holding.
At first glance, it seems that it is not necessary to play or stop the game, but since Piste Roadbook Reader assigns the key code itself, it is confusing that there is a button that allows you to press and hold to repeat, and a button that does not repeat when you press and hold.

In roadbook apps
Rally Roadbook Reader
F2R Rally Tripmeter
This setting is available in .
Piste Roadbook Reader allows you to freely assign key codes within the app, so there is no problem with the above settings.

By improving it, it will be in media and roadbook mode.

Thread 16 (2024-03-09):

DMD Mode Proposal

harupipapaZZZ, 2024-03-09:
The current DMD mode is
const uint8_t DMD_KEY_UP = HID_KEY_ARROW_UP;
const uint8_t DMD_KEY_DOWN = HID_KEY_ARROW_DOWN;
const uint8_t DMD_KEY_LEFT = HID_KEY_ARROW_LEFT;
const uint8_t DMD_KEY_RIGHT = HID_KEY_ARROW_RIGHT;
const uint8_t DMD_KEY_CENTER = HID_KEY_ENTER;
const uint8_t DMD_KEY_A = HID_KEY_F5;
const uint8_t DMD_KEY_B = HID_KEY_F6;
const uint8_t DMD_KEY_VIRTUAL = HID_KEY_F7;
is set to .
I know this is based on the definition of CONTROLLER TYPES AND KEY CODES in DMD.

However, when you actually use it, there are some problems.
F7 zooms out, but it requires a long press of the center button, which makes it difficult to use.

It would be good to improve it like this.

const uint8_t DMD_KEY_UP = HID_KEY_ARROW_UP;
const uint8_t DMD_KEY_DOWN = HID_KEY_ARROW_DOWN;
const uint8_t DMD_KEY_LEFT = HID_KEY_ARROW_LEFT;
const uint8_t DMD_KEY_RIGHT = HID_KEY_ARROW_RIGHT;
const uint8_t DMD_KEY_CENTER = HID_KEY_ENTER;
const uint8_t DMD_KEY_A = HID_KEY_EQUAL;(Button A on DMD)
const uint8_t DMD_KEY_B = HID_KEY_MINUS;(Button B on DMD)
const uint8_t DMD_KEY_VIRTUAL = HID_KEY_D;(Displayed in the bottom menu ◁▷ on DMD)
It is easier to use if you change it to .

Although not official, DMD also works with multiple keycodes.
See here
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

Furthermore
Add long press of A button and long press of B button respectively.
const uint8_t DMD_KEY_VIRTUAL_A = HID_KEY_N;
(No setting in DMD)
const uint8_t DMD_KEY_VIRTUAL_B = HID_KEY_C;
(Same as ENTER in DMD)

You should now be able to control DMD, OSMAND, MRA, and the Android home screen.

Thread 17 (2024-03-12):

IP68 rated 5-way navigation switch from Digikey

MotoMongrel, 2024-03-12:
Are you able to fix the link to the IP68 rated 5-way navigation switch from Digikey, it's coming up with a 404 error. Thanks

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

harupipapaZZZ, 2024-03-13:
May no longer be available at Digikey.
I think this is the same thing.
Luffy Controls HS-1 5way Castle Cap
https://ruffycontrols.com/product/hs1-series/

MotoMongrel, 2024-03-13:
> May no longer be available at Digikey. I think this is the same thing. Luffy Controls HS-1 5way Castle Cap https://ruffycontrols.com/product/hs1-series/

Thanks for that, I'll check it out.

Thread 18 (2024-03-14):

Developing a key mapping app that does not require mode changes

harupipapaZZZ, 2024-03-14:
Although it is not directly related to the function of the moto button,
When using it, it is very troublesome to change the mode according to the purpose.
Carpeiter, DMD Remote One, Silver FOX, etc. use dedicated remote control button apps.

without changing remote mode.
I'm running an app that uses pressed buttons to emulate keycodes and gestures.
The point is that it works depending on the app you use.

It is similar to key mappers, AUTOMATE, etc.
The advantage of apps that are available by default is that users do not need to configure them themselves.

However, it would be troublesome for the creator to create all the mappings, so I think it would be nice to have a function that allows you to create them yourself.
Select an app, press a button, and specify an action.
Easy if possible.

AUTOMATE and KEY mappers are complex because they can perform a variety of operations.
Therefore, we narrowed down the functions to match the Moto button.
An app like this would be even more convenient.

I can't develop it, so please have joncox123 create it.

downerhouse, 2024-09-25:
If you use Android, there is already an app available where you can do this - and this was partly my motivation for making the code changes I described in another thread.  I have changed the code to only give me a mouse mode, and media mode, and made it easier to switch between the 2.

I have then modified the mouse mode so that the A and B buttons are pushing  key codes to my phone that are then intercepted by the Key Mapper app.  You can make the mappings App specific based on what is running in the foreground on the phone.  Therefore the behaviour change is totally user controllable without having to keep changing the Motobuttons source code.

If you use an iPhone, I have no idea if this is possible.

Please see my comments in the issue I created relating to Fusion 360 files.

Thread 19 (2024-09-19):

Fusion 360 CAD files & 3d printing offer to anyone who needs it.

downerhouse, 2024-09-19:
Was hoping to upload this into this site, but do not have access.

Attached is the CAD file in Fusion 360 for the box and changes needed for the MotoButtons project.

I can also upload the 3d printing STL's project files if anyone needs them.

I'm also happy to 3d print the box / gasket for anyone for a small fee plus postage cost - only enough to cover my costs.  Anybody who wants to take me up on this, please email me.  Address is visible via my profile.

[Joystick Box.zip](https://github.com/user-attachments/files/17062979/Joystick.Box.zip)

downerhouse, 2024-09-25:
Quick update on my post above.  Since I posted the basic Fusion 360 file, I have now created a version of Motobuttons using a 3d printed case, and it incorporates a number of improvements to the base Motobuttons design.  Such improvements include:

1. A specially designed holder for the board, which is sandwiched into place when the lid is screwed on so the board is nice and snug and cannot move, and is held away from the other components.
2. An improved design on how the joystick is mounted - which increases the strength of the adhesion and improves water proofing.
3. Made the box slightly bigger to make it a bit easier to wire, and fit all components inside.
4. Have made it easy to use both on bike power and to make it very easy to perform USB updates using a magnetic mounting adapter and 4 pin cable connector.  I have both a USB A cable with the opposing 4 pin connector on it, and the bike power cable has the same 4 pin connector, but utilises only +/-.  The bike cable incorporates a simple 12v -> 5v regulator.

In addition, I have taken the base code, and modified it to suit my own purposes - have removed the DMD and MRA profiles, and modified the mouse mode and media modes to exactly suit my needs (on an Android bike setup).

If anyone is interested in my modifications, I am happy to share.  My email address is available via my profile.

harupipapaZZZ, 2025-03-07:
I'm interested in the new design of the downerhouse.
I've emailed you.

downerhouse, 2025-03-07:
Hi, I'll send you the 3d printing files and esp32 code in the next day or so.

Steve

Sent from Outlook for Android<https://aka.ms/AAb9ysg>
________________________________
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

downerhouse, 2025-03-09:
Hi, can you let me know your email address to send the files to.  I have them ready in a zip file.

Thanks

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

harupipapaZZZ, 2025-03-09:
downerhouse
Please email us here

swdaswda@yahoo.co.jp

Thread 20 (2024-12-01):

Compilation error: bluefruit.h: No such file or directory

Urrie1974, 2024-12-01:
hello i get an error when uploading the ino file in arduino.

/Users/......./Downloads/MotoButtonsLite/MotoButtonsLite.ino:6:10: fatal error: bluefruit.h: No such file or directory
 #include <bluefruit.h>
          ^~~~~~~~~~~~~
compilation terminated.
exit status 1

Compilation error: bluefruit.h: No such file or directory

What can I do?

Thanks

AVE1906, 2025-01-07:
install Seeed nrf embed enabled boards, press reset button once on board, press reset button twice to set in bootloader mode. I got the same error and this helped.

Remieknaapen, 2025-01-09:
I'm having the same problem. I can upload a simple blink sketch to the board. But the files <bluefruit.h>
#include <Adafruit_LittleFS.h>
#include <InternalFileSystem.h>
#include <Adafruit_TinyUSB.h>
#include <stdlib.h>

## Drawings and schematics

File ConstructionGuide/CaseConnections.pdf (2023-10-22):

# Inside View of Case

### Switch and LED Wiring

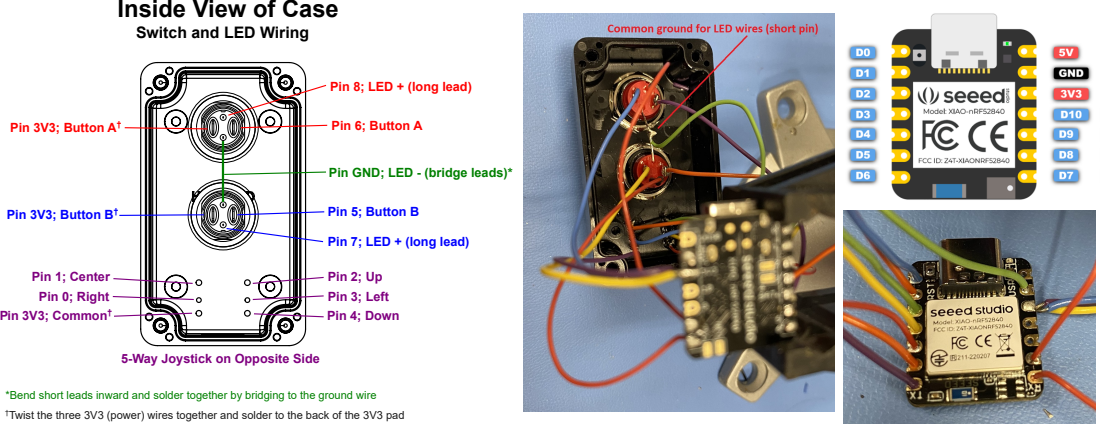
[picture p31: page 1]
Pin 6; Button A; Pin 5; Button B; Pin 3V3; Button A†; Pin 3V3; Button B†; Pin 3V3; Common†; Pin 0; Right; Pin 1; Center; Pin 4; Down; Pin 3; Left; Pin 2; Up

Pin 8; LED + (long lead)

Pin GND; LED - (bridge leads)*

Pin 7; LED + (long lead)

5-Way Joystick on Opposite Side

*Bend short leads inward and solder together by bridging to the ground wire
Twist the three 3V3 (power) wires together and solder to the back of the 3V3 pad

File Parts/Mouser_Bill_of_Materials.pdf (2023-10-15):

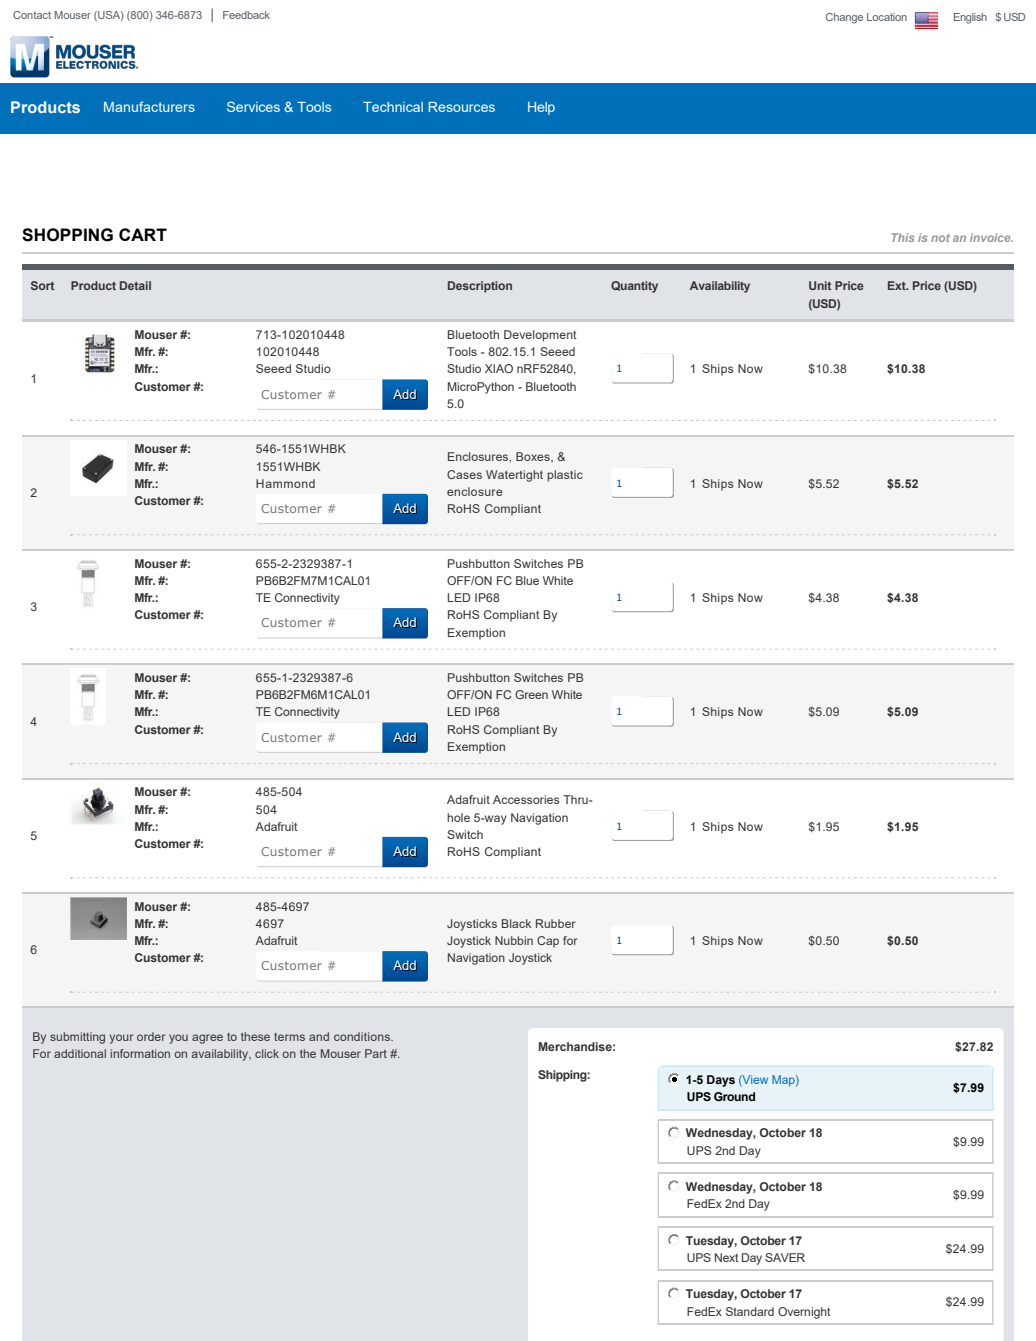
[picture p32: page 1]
Mouser #:; Mfr. #:; Mfr.:; Seeed Studio; Customer #:; Bluetooth Development; Tools 802.15.1 Seeed; Studio XIAO nRF52840,; MicroPython Bluetooth; 1 Ships Now; 546-1551WHBK; 1551WHBK; Hammond; PB6B2FM7M1CAL01; TE Connectivity; PB6B2FM6M1CAL01; Adafruit; Sort; Product Detail; Description; Quantity; Availability; Unit Price; (USD); SHOPPING CART; This is not an invoice.; For additional information on availability, click on the Mouser Part #.; Merchandise:; Shipping:; 1-5 Days (View Map)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

Ext. Price (USD)

Enclosures, Boxes, &
Cases Watertight plastic
enclosure
RoHS Compliant

Pushbutton Switches PB
OFF/ON FC Blue White
LED IP68
RoHS Compliant By
Exemption

OFF/ON FC Green White

Adafruit Accessories Thru-
hole 5-way Navigation
Switch

Joysticks Black Rubber
Joystick Nubbin Cap for
Navigation Joystick

By submitting your order you agree to these terms and conditions. (https://www.mouser.com/saleterms)

Tuesday, October 17
UPS Next Day SAVER

FedEx Standard Overnight

Subtotal: | $35.81

Checkout

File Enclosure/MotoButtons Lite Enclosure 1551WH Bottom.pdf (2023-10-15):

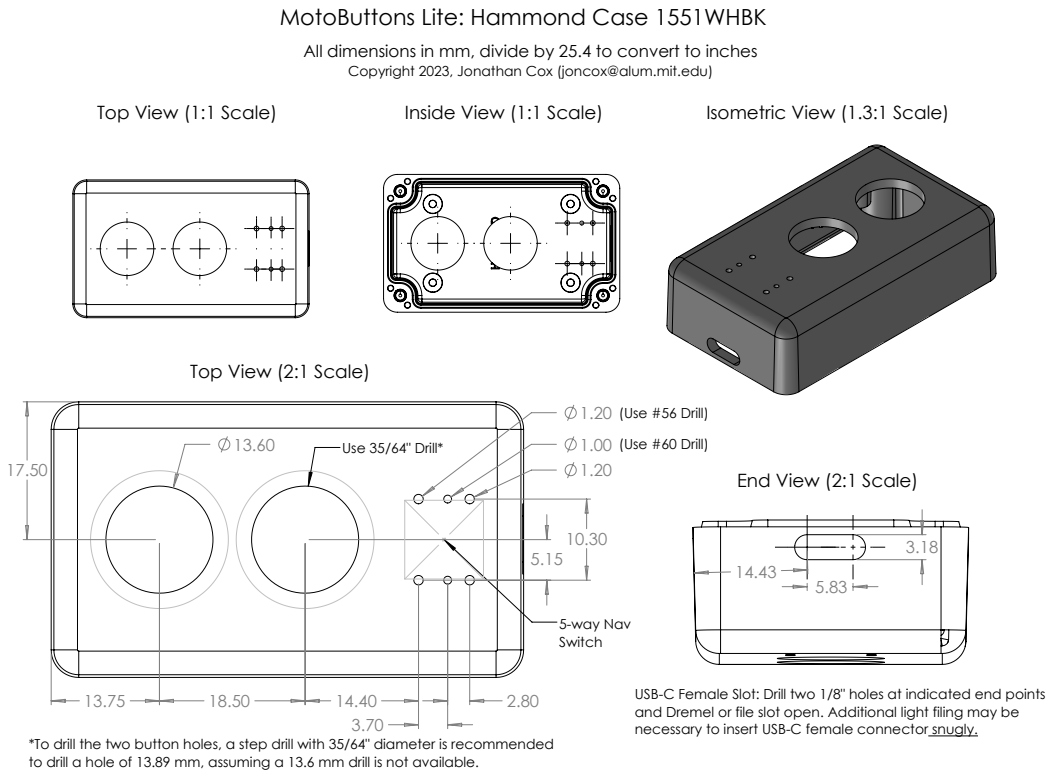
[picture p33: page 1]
5-way Nav; Use 35/64" Drill*; Top View (1:1 Scale); Inside View (1:1 Scale); Isometric View (1.3:1 Scale); (Use #56 Drill); (Use #60 Drill)

MotoButtons Lite: Hammond Case 1551WHBK
All dimensions in mm, divide by 25.4 to convert to inches
Copyright 2023, Jonathan Cox (joncox@alum.mit.edu)

Top View (2:1 Scale)

End View (2:1 Scale)

USB-C Female Slot: Drill two 1/8" holes at indicated end points
and Dremel or file slot open. Additional light filing may be
necessary to insert USB-C female connector snugly.

*To drill the two button holes, a step drill with 35/64" diameter is recommended
to drill a hole of 13.89 mm, assuming a 13.6 mm drill is not available.

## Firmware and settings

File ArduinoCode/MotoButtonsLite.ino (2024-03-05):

/*********************************************************************
License: GNU GENERAL PUBLIC LICENSE; Version 3, 29 June 2007
Version: 1.3 with support for the following modes: DMD2, mouse cursor, MyRoute App, media (music)
Device: Seeed XIAO nRF52840
*********************************************************************/
#include <bluefruit.h>
#include <Adafruit_LittleFS.h>
#include <InternalFileSystem.h>
#include <Adafruit_TinyUSB.h>
#include <stdlib.h>

using namespace Adafruit_LittleFS_Namespace;

// Enable serial debugging (turn this off if not connected to PC)
#define DEBUG false

// How long to wait until DFU reset mode is activated
#define MODE_RESET_MS 15000

// Orientation of controller
#define DEFAULT_BUTTON_MAP 2
uint8_t buttonOrientation = DEFAULT_BUTTON_MAP;

// how long to inactivate up/down/left/right on joystick when center is pressed
#define BUTTON_CENTER_TIMEOUT 500 // ms

/*----- Persistent Storage Filesystem -----*/
// This is used to store settings, such as the last mode
#define FILENAME    "/MotoButtons.set"
File file(InternalFS);

// BLE classes
BLEDis bledis;
BLEHidAdafruit blehid;

// BLE configuration
#define BLE_TX_POWER 8
const char BLE_DEVICE_NAME[] = "DMD2 CTL 8K";
const char BLE_DEVICE_MODEL[] = "MotoButtons 1.3";
const char BLE_MANUFACTURER[] = "Me";
bool BLE_connected = false;

/* 
 * --------------------- MODE CONFIGURATION ----------------------------
 * 	DMD2: up/down/left/right arrows, enter, F6 and F7
 * 	Mouse: mouse up/down/left/right, left click, left click, ?
 * 	MyRouteApp: up/down/left/right arrows, 'c', -, +, longpress center for 'n' (hold center for skip waypoint)
 *  Media (music): vol up, vol down, previous track, next track, mute, play/pause, stop
 */
// Selected Mode: indicates the currently selected operating mode
#define MODE_TOGGLE_MS 1000
#define N_MODES 4
enum Mode {
	mouse = 0,
  DMD2  = 1,
	MRA   = 2,
  MEDIA = 3
};
enum Mode currentMode;

bool modeButtonsReleased = true;

/* DMD2 Mode Configuration */
// https://www.drivemodedashboard.com/controller-implementation-guide/
// https://arduino.stackexchange.com/questions/65513/how-do-i-send-non-ascii-keys-over-the-ble-hid-connection-using-an-adafruit-nrf52
// https://github.com/adafruit/Adafruit_nRF52_Arduino/blob/200b3aaefb3256ac26df82ebc9b5b58923d9c37c/cores/nRF5/Adafruit_TinyUSB_Core/tinyusb/src/class/hid/hid.h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
// https://github.com/adafruit/Adafruit_nRF52_Arduino/issues/785
// Key codes to send for button presses:
const uint8_t DMD_KEY_UP      = HID_KEY_ARROW_UP;
const uint8_t DMD_KEY_DOWN    = HID_KEY_ARROW_DOWN;
const uint8_t DMD_KEY_LEFT    = HID_KEY_ARROW_LEFT;
const uint8_t DMD_KEY_RIGHT   = HID_KEY_ARROW_RIGHT;
const uint8_t DMD_KEY_CENTER  = HID_KEY_ENTER;
const uint8_t DMD_KEY_A       = HID_KEY_F5;
const uint8_t DMD_KEY_B       = HID_KEY_F6;
const uint8_t DMD_KEY_VIRTUAL = HID_KEY_F7;

/* Mouse Mode Configuration */
#define MOUSE_RATE_SLOW 10
#define MOUSE_RATE_FAST 40
#define MOUSE_RATE_DELAY 500
bool mouse_left_button_pressed = false;
const uint8_t MOUSE_KEY_A     = HID_KEY_ENTER;

/* MyRouteApp Mode Configuration */
const uint8_t MRA_KEY_UP      = HID_KEY_ARROW_UP;
const uint8_t MRA_KEY_DOWN    = HID_KEY_ARROW_DOWN;
const uint8_t MRA_KEY_LEFT    = HID_KEY_ARROW_LEFT;
const uint8_t MRA_KEY_RIGHT   = HID_KEY_ARROW_RIGHT;
const uint8_t MRA_KEY_CENTER  = HID_KEY_C;
const uint8_t MRA_KEY_A       = HID_KEY_KEYPAD_ADD;
const uint8_t MRA_KEY_B       = HID_KEY_MINUS;
const uint8_t MRA_KEY_VIRTUAL = HID_KEY_N; // long press for skip waypoint

/* Media Mode Configuration */
const uint8_t MEDIA_KEY_UP      = HID_USAGE_CONSUMER_VOLUME_INCREMENT; // volume up
const uint8_t MEDIA_KEY_DOWN    = HID_USAGE_CONSUMER_VOLUME_DECREMENT; // volume down
const uint8_t MEDIA_KEY_LEFT    = HID_USAGE_CONSUMER_SCAN_PREVIOUS; // previous song
const uint8_t MEDIA_KEY_RIGHT   = HID_USAGE_CONSUMER_SCAN_NEXT; // next song 
const uint8_t MEDIA_KEY_CENTER  = HID_USAGE_CONSUMER_MUTE; // Mute
const uint8_t MEDIA_KEY_A       = HID_USAGE_CONSUMER_PLAY_PAUSE; // play - pause
const uint8_t MEDIA_KEY_B       = HID_USAGE_CONSUMER_STOP; // stop music
/*---------------------- END MODE CONFIGURATION ----------------------*/

/*----------------- BUTTON CONFIGURATION AND LOGIC -------------------*/
/* BLE key report */
#define N_KEY_REPORT 6
uint8_t keyReport[N_KEY_REPORT] = {HID_KEY_NONE, HID_KEY_NONE, HID_KEY_NONE, HID_KEY_NONE, HID_KEY_NONE, HID_KEY_NONE};
bool keyReportChanged = false;
bool forceKeyReport = false; // used to force another key report for key up activation events

// Digital IO pin mapping (default)
uint8_t BUTTON_UP      = 4;
uint8_t BUTTON_DOWN    = 2;
uint8_t BUTTON_LEFT    = 0;
uint8_t BUTTON_RIGHT   = 3;
uint8_t BUTTON_CENTER  = 1;
uint8_t BUTTON_A       = 5;
uint8_t BUTTON_B       = 6;
uint8_t LED_BUTTON_A   = 7;
uint8_t LED_BUTTON_B   = 8;

#define DEBOUNCE_TIME_MS 50

// state of buttons
bool button_up_state      = false;
bool button_down_state    = false;
bool button_left_state    = false;
bool button_right_state   = false;
bool button_center_state  = false;
bool button_A_state       = false;
bool button_B_state       = false;
bool button_virtual_state = false; // 8th virtual button activated via long press

// prior state of button reading for debouncing purposes
bool button_up_state_prior      = false;
bool button_down_state_prior    = false;
bool button_left_state_prior    = false;
bool button_right_state_prior   = false;
bool button_center_state_prior  = false;
bool button_A_state_prior       = false;
bool button_B_state_prior       = false;

// Record state change of buttons to be used to monitor when event is transmitted
bool button_up_flipped      = false;
bool button_down_flipped    = false;
bool button_left_flipped    = false;
bool button_right_flipped   = false;
bool button_center_flipped  = false;
bool button_A_flipped       = false;
bool button_B_flipped       = false;
bool button_virtual_flipped = false;

// a flag to indicate that virtual button was released, for center timeout purposes only
bool button_virtual_timeout = false;

// last time that button transitioned from low to high
unsigned long button_up_time      = 0;
unsigned long button_down_time    = 0;
unsigned long button_left_time    = 0;
unsigned long button_right_time   = 0;
unsigned long button_center_time  = 0;
unsigned long button_A_time       = 0;
unsigned long button_B_time       = 0;
unsigned long button_virtual_time = 0;
/*------------------- END BUTTON CONFIG & LOGIC-----------------------*/

// At startup, the user can hold down a joystick direction to select an orientation
// -1 indicates no valid selection was made
int getButtonMapSelection() {
	// Read all four directions because we can only allow a mode switch if
	// one direction is pressed
	uint8_t up = digitalRead(BUTTON_UP);
	uint8_t down = digitalRead(BUTTON_DOWN);
	uint8_t left = digitalRead(BUTTON_LEFT);
	uint8_t right = digitalRead(BUTTON_RIGHT);
	
	if (up + down + left + right > 1) {
		// user held down more than one direction, return the default mapping
		return -1;
	}
	
	if (up)
		return 2;
	if (down)
		return 0;
	if (left)
		return 1;
	if (right)
		return 3;
	
	// no selection was made
	return -1;	
}

/* Change the mapping of buttons based on a map specifier, buttMap
 * butMapp:
 * 	0: UP is GPIO pin 2
 *  1: UP is GPIO pin 3
 *  2: UP is GPIO pin 4
 *  3: UP is GPIO pin 0
 */
bool setButtonMapping(uint8_t buttMap) {
	switch (buttMap) {
	case 0: // two button on top
		BUTTON_UP      = 2;
		BUTTON_DOWN    = 4;
		BUTTON_LEFT    = 3;
		BUTTON_RIGHT   = 0;
		BUTTON_CENTER  = 1;
		BUTTON_A       = 6;
		BUTTON_B       = 5;
		LED_BUTTON_A   = 8;
		LED_BUTTON_B   = 7;
		break;
	case 1: // two button on left
		BUTTON_UP      = 0;
		BUTTON_DOWN    = 3;
		BUTTON_LEFT    = 2;
		BUTTON_RIGHT   = 4;
		BUTTON_CENTER  = 1;
		BUTTON_A       = 6;
		BUTTON_B       = 5;
		LED_BUTTON_A   = 8;
		LED_BUTTON_B   = 7;
		break;
	case 2: // two button on bottom
		BUTTON_UP      = 4;
		BUTTON_DOWN    = 2;
		BUTTON_LEFT    = 0;
		BUTTON_RIGHT   = 3;
		BUTTON_CENTER  = 1;
		BUTTON_A       = 5;
		BUTTON_B       = 6;
		LED_BUTTON_A   = 7;
		LED_BUTTON_B   = 8;
		break;
	case 3: // two buttons toward right
		BUTTON_UP      = 3;
		BUTTON_DOWN    = 0;
		BUTTON_LEFT    = 4;
		BUTTON_RIGHT   = 2;
		BUTTON_CENTER  = 1;
		BUTTON_A       = 6;
		BUTTON_B       = 5;
		LED_BUTTON_A   = 8;
		LED_BUTTON_B   = 7;
		break;
	default:
		return true;
	}

	return false;
}

// This function returns true if the center button is in an active state
// if so, the program should ignore up/down/left/right on the joystick
bool isCenterActive() {
	if (button_center_state)
		return true;
	if (digitalRead(BUTTON_CENTER))
		return true;
	if (millis() - button_center_time < BUTTON_CENTER_TIMEOUT)
		return true;
	
	return false;
}


bool isVirtualActive() {
	if (millis() - button_virtual_time < BUTTON_CENTER_TIMEOUT)
		return true;
	
	return button_virtual_state;
}

//if  This function should be called rapidly in a loop to update the debounce filter and key state
// https://docs.arduino.cc/built-in-examples/digital/Debounce
bool debounceButton(unsigned int button, bool *state, bool *priorState, bool *buttonFlipped,
                    unsigned long *debounceTime, const char *buttonName) {
  bool reading;
  unsigned long readTime;
  bool stateChanged = false;

  reading = digitalRead(button);
  readTime = millis();

  // If reading has changed, switch has not settled yet
  if (reading != *priorState)
    *debounceTime = readTime;
  // State has been stable for time exceeding debounce filter delay, so update state
  else if ((readTime - *debounceTime) > DEBOUNCE_TIME_MS)
    // If state changed after debounce, new state has not yet been transmitted
    if (reading != *state) {
      stateChanged = true;
      *state = reading;
      *buttonFlipped = true;
    }
    *priorState = reading;

    return stateChanged;
}

void releaseAllKeys() {
  uint8_t keyReportRelease[N_KEY_REPORT] = {HID_KEY_NONE, HID_KEY_NONE , HID_KEY_NONE , HID_KEY_NONE , HID_KEY_NONE , HID_KEY_NONE};
  blehid.keyboardReport(0, keyReportRelease);
}

void indicateMode(uint8_t mode, bool led) {
    // signal the new mode number
    for (unsigned int i = 0; i < 2*((int)mode+1); i++) {
		if (led)
			digitalToggle(LED_BUTTON_A);
		else
			digitalToggle(LED_BUTTON_B);
      delay(500);
    }
    digitalWrite(LED_BUTTON_A, LOW);
    digitalWrite(LED_BUTTON_B, LOW);
}

void updateButtons() {
  bool stateChanged = false;
  
  // Read the state of all physical buttons
  stateChanged |= debounceButton(BUTTON_UP, &button_up_state, &button_up_state_prior, &button_up_flipped, &button_up_time, "UP");
  stateChanged |= debounceButton(BUTTON_DOWN, &button_down_state, &button_down_state_prior, &button_down_flipped, &button_down_time, "DOWN");
  stateChanged |= debounceButton(BUTTON_LEFT, &button_left_state, &button_left_state_prior, &button_left_flipped, &button_left_time, "LEFT");
  stateChanged |= debounceButton(BUTTON_RIGHT, &button_right_state, &button_right_state_prior, &button_right_flipped, &button_right_time, "RIGHT");
  stateChanged |= debounceButton(BUTTON_CENTER, &button_center_state, &button_center_state_prior, &button_center_flipped, &button_center_time, "CENTER");
  stateChanged |= debounceButton(BUTTON_A, &button_A_state, &button_A_state_prior, &button_A_flipped, &button_A_time, "A");
  stateChanged |= debounceButton(BUTTON_B, &button_B_state, &button_B_state_prior, &button_B_flipped, &button_B_time, "B");
  
  /* ----------- Detect state of virtual buttons ---------------------*/
  if (button_center_state && (millis() - button_center_time > MODE_TOGGLE_MS)) {
	//virtual button activated
    if (!button_virtual_state) {
      if (DEBUG)
        Serial.println("Virtual button activated.");
      button_virtual_time = millis();
      button_virtual_flipped = true;
      stateChanged |= true;

      // indicate virtual button
      digitalToggle(LED_BUTTON_A);
      digitalWrite(LED_BUTTON_A, HIGH);
    }
    button_virtual_state = true;
  }
  else if (button_virtual_state) {
    // virtual button is not active
	button_virtual_flipped = true;
	button_virtual_state = false;
	button_virtual_timeout = true;
	button_virtual_time = millis();
    if (DEBUG) Serial.println("Virtual button deactivated, timeout enabled.");
    digitalToggle(LED_BUTTON_A);
    digitalWrite(LED_BUTTON_A, LOW);
    stateChanged |= true;
  }
  
  // Also, a race condition can occur where the virtual button is released and the center flips from high to low, activating the center
  // Therefore, the release action of the virtual button is to disable the center button for a period of time
  if (button_virtual_timeout)
	button_center_flipped = false;
  if (button_virtual_timeout && (millis() - button_virtual_time > BUTTON_CENTER_TIMEOUT)) {
	button_virtual_timeout = false;
	if (DEBUG) Serial.println("Virtual button timeout disabled.");
  }
	
  /*------------------------------------------------------------------*/

  // Indicate whether any buttons changed state
  keyReportChanged = stateChanged;

  /* Hard reset and enter firmware udpate mode (DFU)
   * This mode is necessary because the bootloader in the Seed nRF52840 has a bug that prevents uploading new software
   * from the Arduino IDE if a BLE sketch is uploaded previously. Thus, it is necessary to enter via triggering a DFU reset event.
   */
  if (button_A_state && button_B_state && (millis() - button_A_time > MODE_RESET_MS) && (millis() - button_B_time > MODE_RESET_MS)) {
    if (DEBUG)
      Serial.println("Resetting and entering firmware update (FDU) mode...");
    enterSerialDfu();
  }

  /*------------------- Handle mode cycling --------------------------*/
  // Check for release of mode cycle button combination
  if (!button_A_state || !button_B_state) {
    modeButtonsReleased = true;
  }

  if (button_A_state && button_B_state && (millis() - button_A_time > MODE_TOGGLE_MS) && (millis() - button_B_time > MODE_TOGGLE_MS) && modeButtonsReleased) {
    // Buttons A and B were both long-pressed, which means we should advance the mode
    currentMode = (Mode)(((int)currentMode + 1) % N_MODES);
    if (DEBUG) {
      Serial.print("Mode advanced to ");
      Serial.println(currentMode);
    }
    
    // Since mode has been changed, inactivate any ongoing key or mouse presses
    releaseAllKeys();
    blehid.mouseButtonRelease();
    modeButtonsReleased = false;

    // store new mode to flash memory
    writeSettings();

	  // Flash the LEDs indicating a change of mode occured
    for (unsigned int i = 0; i < 30; i++) {
      digitalToggle(LED_BUTTON_A);
      digitalToggle(LED_BUTTON_B);
      delay(100);
    }
    digitalWrite(LED_BUTTON_A, LOW);
    digitalWrite(LED_BUTTON_B, LOW);
    delay(1000);
    indicateMode((uint8_t)currentMode, true);
  }
  /*------------------------------------------------------------------*/
}

void mapButtonsToKeyReport() {
	unsigned int i = 0;
	
	bool centerActive = isCenterActive();
	bool virtualActive = isVirtualActive();

	switch (currentMode) {
		case DMD2:
			if (button_up_state && !centerActive) {
			  keyReport[i] = DMD_KEY_UP;
			  ++i;
			}
			if (button_down_state && !centerActive) {
			  keyReport[i] = DMD_KEY_DOWN;
			  ++i;
			}
			if (button_left_state && !centerActive) {
			  keyReport[i] = DMD_KEY_LEFT;
			  ++i;
			}
			if (button_right_state && !centerActive) {
			  keyReport[i] = DMD_KEY_RIGHT;
			  ++i;
			}
			if (!button_center_state && button_center_flipped && !virtualActive) {
			  button_center_flipped = false;
			  forceKeyReport = true;
			  keyReport[i] = DMD_KEY_CENTER;
			  ++i;
			}
			if (button_A_state & button_A_flipped && !button_B_state) {
			  button_A_flipped = false;
			  keyReport[i] = DMD_KEY_A;
			  ++i;
			}
			if (button_B_state && button_B_flipped && !button_A_state && (i < N_KEY_REPORT)) {
			  button_B_flipped = false;
			  keyReport[i] = DMD_KEY_B;
			  ++i;
			}
			if (button_virtual_state && (i < N_KEY_REPORT) && button_virtual_flipped) {
			  button_virtual_flipped = false;
			  keyReport[i] = DMD_KEY_VIRTUAL;
			  ++i;
			}
			break;

		case mouse:
			if (button_A_state && button_A_flipped) {
			  keyReport[0] = MOUSE_KEY_A;
			  ++i;
			  button_A_flipped = false;
			}
			break;

		case MRA:
			if (button_up_state && !centerActive) {
		      if (DEBUG) Serial.println("MRA UP");
			  keyReport[i] = MRA_KEY_UP;
			  ++i;
			}
			if (button_down_state && !centerActive) {
			  if (DEBUG) Serial.println("MRA DOWN");
			  keyReport[i] = MRA_KEY_DOWN;
			  ++i;
			}
			if (button_left_state && !centerActive) {
			  if (DEBUG) Serial.println("MRA LEFT");
			  keyReport[i] = MRA_KEY_LEFT;
			  ++i;
			}
			if (button_right_state && !centerActive) {
			  if (DEBUG) Serial.println("MRA RIGHT");
			  keyReport[i] = MRA_KEY_RIGHT;
			  ++i;
			}
			if (!button_center_state && button_center_flipped && !virtualActive) {
			  if (DEBUG) Serial.println("MRA CENTER");
			  button_center_flipped = false;
			  forceKeyReport = true;
			  keyReport[i] = MRA_KEY_CENTER;
			  ++i;
			}
			if (button_A_state && button_A_flipped && !button_B_state) {
			  if (DEBUG) Serial.println("MRA A");
			  button_A_flipped = false;
			  keyReport[i] = MRA_KEY_A;
			  ++i;
			}
			if (button_B_state && button_B_flipped && !button_A_state && (i < N_KEY_REPORT)) {
			  if (DEBUG) Serial.println("MRA B");
			  button_B_flipped = false;
			  keyReport[i] = MRA_KEY_B;
			  ++i;
			}
			if (button_virtual_state && (i < N_KEY_REPORT) && button_virtual_flipped) {
			  if (DEBUG) Serial.println("MRA VIRTUAL");
			  button_virtual_flipped = false;
			  keyReport[i] = MRA_KEY_VIRTUAL;
			  ++i;
			}
			break;
    
    case MEDIA:
    // the media keys must be reported via a different ("consumer") function to work on iOS
			if (button_up_state && !centerActive) {
		    if (DEBUG) Serial.println("Media key UP");
			  blehid.consumerKeyPress(0, MEDIA_KEY_UP);
        blehid.consumerKeyRelease(0);
			  ++i;
			}
			if (button_down_state && !centerActive) {
			  if (DEBUG) Serial.println("Media key DOWN");
			  blehid.consumerKeyPress(0, MEDIA_KEY_DOWN);
        blehid.consumerKeyRelease(0);
			  ++i;
			}
			if (button_left_state && !centerActive) {
			  if (DEBUG) Serial.println("Media key LEFT");
			  blehid.consumerKeyPress(0, MEDIA_KEY_LEFT);
        blehid.consumerKeyRelease(0);
			  ++i;
			}
			if (button_right_state && !centerActive) {
			  if (DEBUG) Serial.println("Media key RIGHT");
			  blehid.consumerKeyPress(0, MEDIA_KEY_RIGHT);
        blehid.consumerKeyRelease(0);
			  ++i;
			}
			if (!button_center_state && button_center_flipped && !virtualActive) {
			  if (DEBUG) Serial.println("Media key CENTER");
			  button_center_flipped = false;
			  forceKeyReport = true;
			  blehid.consumerKeyPress(0, MEDIA_KEY_CENTER);
        blehid.consumerKeyRelease(0);
			  ++i;
			}
			if (button_A_state && button_A_flipped && !button_B_state) {
			  if (DEBUG) Serial.println("Media key A");
			  button_A_flipped = false;
			  blehid.consumerKeyPress(0, MEDIA_KEY_A);
        blehid.consumerKeyRelease(0);
			  ++i;
			}
			if (button_B_state && button_B_flipped && !button_A_state && (i < N_KEY_REPORT)) {
			  if (DEBUG) Serial.println("Media key B");
			  button_B_flipped = false;
			  blehid.consumerKeyPress(0, MEDIA_KEY_B);
        blehid.consumerKeyRelease(0);
			  ++i;
			}
			break;

		default:
			break;
	}
	
	for (unsigned int j = i; j < N_KEY_REPORT; j++) {
		keyReport[j] = HID_KEY_NONE;
	}
}

void handleMouse() {
    // handle mouse click release
    if ((!button_center_state && button_center_flipped) || (!button_B_state && button_B_flipped) && mouse_left_button_pressed) {
      blehid.mouseButtonRelease();
      button_center_flipped = false;
      button_B_flipped = false;
      mouse_left_button_pressed = false;
    }

      // Handle click
      if ((button_center_state && button_center_flipped) || (button_B_state && button_B_flipped) && !mouse_left_button_pressed) {
        blehid.mouseButtonPress(MOUSE_BUTTON_LEFT);
        button_center_flipped = false;
        button_B_flipped = false;
        mouse_left_button_pressed = true;
      }

      // Move pointer
      if (!isCenterActive()) {
        int rate = MOUSE_RATE_SLOW;
        unsigned long currTimeMs = millis();
        if (((currTimeMs - button_up_time > MOUSE_RATE_DELAY) && button_up_state) ||
            ((currTimeMs - button_down_time > MOUSE_RATE_DELAY) && button_down_state) ||
            ((currTimeMs - button_left_time > MOUSE_RATE_DELAY) && button_left_state) ||
            ((currTimeMs - button_right_time > MOUSE_RATE_DELAY) && button_right_state))
          rate = MOUSE_RATE_FAST;
        else
          rate = MOUSE_RATE_SLOW;

        if (button_up_state)
          blehid.mouseMove(0, -rate);
        if (button_down_state)
          blehid.mouseMove(0, rate);
        if (button_left_state)
          blehid.mouseMove(-rate, 0);
        if (button_right_state)
          blehid.mouseMove(rate, 0);
      }
}
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
void loop() 
{
  // Indicate whether the device is connected and running
  if (!BLE_connected && (Bluefruit.connected() > 0)) {
    if (DEBUG)
      Serial.println("BLE connected to host.");
    digitalWrite(LED_BUTTON_A, LOW);
    digitalWrite(LED_BUTTON_B, LOW);
    BLE_connected = true;
  }
  else if (Bluefruit.connected() == 0) {
    digitalToggle(LED_BUTTON_A);
    digitalToggle(LED_BUTTON_B);
    delay(200);
    BLE_connected = false;
  }

  // Read current state of buttons
  updateButtons();
  
  if (BLE_connected) {
	  // Compile the BLE HID key report
	  if (keyReportChanged || forceKeyReport) {
      forceKeyReport = false;
      mapButtonsToKeyReport();
      blehid.keyboardReport(0, keyReport);
      if (DEBUG) Serial.println("Key report sent.");
	  }
	  
	  if (currentMode == mouse)
		  handleMouse();
  }
}

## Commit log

2023-10-15 Create MotoButtonsLite.ino
    This code has not yet been tested on an actual device, it is just an initial prototype that compiles :)
2023-10-15 Add files via upload
    case construction schematics
2023-10-22 Update MotoButtonsLite.ino
    mouse mode working well, but still need to fix some issues getting DMD2 to recognized key presses in DMD2 mode
    [MotoButtonsLite.ino]
2023-10-22 Update MotoButtonsLite.ino
    fixed bugs in mouse mode and keycode for enter. verified that key events are being received correctly, but DMD2 is not recognizing device
    [MotoButtonsLite.ino]
2023-10-22 Update MotoButtonsLite.ino
    mouse mode and DMD2 mode working, but still some issues when toggling modes (stray button activations)
    [MotoButtonsLite.ino]
2023-10-22 Update MotoButtonsLite.ino
    added BLE connection indicator for LEDs
2023-10-25 Update MotoButtonsLite.ino
    -added support for multiple modes, including MRA
    -improved mouse mode control
    -improved mode indication LED flashing
    -added support for an 8th virtual button (long press)
2023-10-30 Update MotoButtonsLite.ino
    fixed issue where code was hanging on boot for serial port
    [MotoButtonsLite.ino]
2023-11-01 Update MotoButtonsLite.ino
    fixed issues with joystick center usability
    [MotoButtonsLite.ino]
2023-11-02 Update MotoButtonsLite.ino
    fixed virtual button release handing
    [MotoButtonsLite.ino]
2024-03-05 Update MotoButtonsLite.ino
    bug fix for media key reporting for ios
    [MotoButtonsLite.ino]
